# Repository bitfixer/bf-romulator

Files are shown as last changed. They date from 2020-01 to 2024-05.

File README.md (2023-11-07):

# bf-romulator
Romulator - RAM/ROM replacement and debug for 6502 and Z80 CPU systems

romulator - verilog code to implement ROMulator RAM/ROM replacement

programmer - programmer and console application for updating ROMulator, and debug

tools - C++ tools for building firmware images for ROMulator

## About

The ROMulator is a RAM/ROM replacement device for 6502 and Z80 systems, with programmable memory maps and debug functionality which allows you to halt a running CPU and read from or write to memory. See https://bitfixer.com/romulator for more information.

This Readme mostly covers the 6502 version for now, more documentation coming soon for Z80.

## Installation

To use the ROMulator, first remove the 6502 CPU from its socket on the PET (or other computer)'s motherboard.
**Note the orientation of the notch on the 6502 chip in the socket.**
Insert the 6502 chip into the 40-pin socket on the ROMulator board. Make sure the notch on the chip is aligned with the notch on the ROMulator socket.
Then, take the ROMulator board, and using the pins on the underside of the board, insert it into the 6502 socket on the motherboard.
**Make sure the notch on the 6502 chip is pointing in its original direction.**
If the ROMulator is inserted backwards, this may damage the ROMulator board since 5v will be presented where it shouldn't be.
Just make sure to double check:
- Original orientation of 6502
- 6502 chip notch should match with notch in ROMulator socket
- When inserting ROMulator into 6502 socket, 6502 chip should be in its original orientation

## Default Switch Settings

The ROMulator supports up to 32 memory maps. The default memory maps shipped with the ROMulator are currently mostly related to the Commodore PET, but you can add any maps you want via the programming interface. Over time more configurations for common 6502 computers will be added. Please note that these settings reflect the head commit of the repository, and may differ from the default settings on your ROMulator depending on when it was programmed. Building the latest version with `make program` after a `git pull` will generate the settings as described.
The default switch settings are as follows:

|Set Index  |Setting |Switch 1 |Switch 2 |Switch 3 |Switch 4 |
|---|---|---|---|---|---|
|0 |BASIC 2, NON-CRTC, Business Kbd  (i.e. 2001) |Off |Off |Off |Off |
|1 |BASIC 4, NON-CRTC  (i.e. 2001) |On |Off |Off |Off |
|2 |BASIC 4, CRTC, 80C (i.e. 8032) |Off |On |Off |Off |
|3 |BASIC 4, CRTC, 40C (i.e. 4032,4016) |On |On |Off |Off |
|4 |BASIC 4, PET 4032 60Hz |Off |Off |On |Off |
|5 |BASIC 2, NON-CRTC, Normal Kbd (i.e. 2001) |On |Off |On |Off |
|6 |BASIC 4, PET 4032 50Hz |Off |On |On |Off |
|7 |BASIC 4, PET 4016 60Hz |On |On |On |Off |
|8 |Apple II plus |Off |Off |Off |On |
|9 |BASIC 1, PET 2001-8 |On |Off |Off |On |
|10 |VIC-20 PAL |Off |On |Off |On |
|11 |VIC-20 NTSC |On |On |Off |On |
|12 |NOP Generator |Off |Off |On |On |
|13 |PETTESTER |On |Off |On |On |
|14 |PET Low RAM Test |Off |On |On |On |
|15 |PET RAM/ROM/VRAM Test |On |On |On |On |

The memory maps are defined in [config/memory_set_default.csv](config/memory_set_default.csv).
This file indicates which ROMs are located at which memory address.

## Adding Configurations for New 6502 Machines

This topic is big enough to have its own readme, and it is located here:\
[config/README.md](config/README.md)

## Program / Debug

Programming and Debugging with the ROMulator can be done in one of two ways:
- using a Raspberry Pi connected to the ROMulator's 10-pin header, or
- using a standalone programmer consisting of a D1 Mini Board (dev board for ESP12 wifi microcontroller module) and an interface board for connecting to the ROMulator. This method allows uploading new firmware over a wifi network as well as a direct connection to a Win/Linux/Mac using usb.

### Program / Debug with Standalone Programmer over WiFi or USB
Information on programming and debugging using the standalone programmer can be found here:\
[ROMULATOR_STANDALONE.md](ROMULATOR_STANDALONE.md)

### Program / Debug with Raspberry Pi
Programming or Debug functionality of the ROMulator uses a Raspberry Pi using a soft SPI implementation. 
You can use the optional RPI ROMulator programming board, or directly connect the following RPI physical pins to the corresponding pins on the 10-pin header on the ROMulator FPGA board:

|RPI |FPGA Hdr|FPGA Hdr |RPI |
|---|---|---|----|
|19 |1 (MOSI)|2 (3.3v) |17  |
|24 |3 (CS)  |4 (DBG)  |36  |
|22 |5 (RST) |6 (CDONE)|11  |
|23 |7 (SCK) |8 |NC  |
|21 |9 (MISO)|10 (GND) |34  |

If you are only programming and not running the debug client, DBG and CDONE are optional.
Take a look at this wiring diagram for a visual aid:
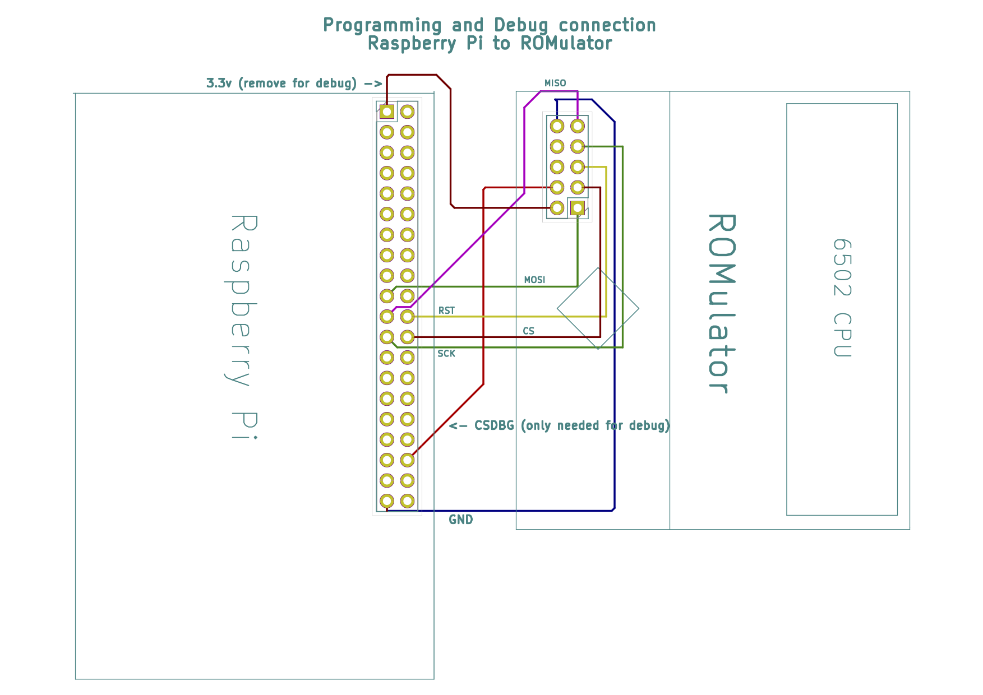
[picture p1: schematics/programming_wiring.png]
programming/debug diagram


# ROMulator programming board

The optional RPI ROMulator programming board is just a breakout board for SPI and UART on the Pi which brings SPI0 and SPI1 pins out to separate headers, as well as a UART header. The ROMulator only uses the SPI0 header. If you received a kit for this board, here are a few quick notes on the assembly.
1. Solder header pins onto the TOP of the board in the section marked 'SPI0'.
2. Solder a 2-pin header onto the header section directly adjacent to SPI0.
3. Solder the 2x20 socket onto the BOTTOM of the board.
4. Connect the jumper onto the 2-pin header for programming. Remove for debug.
5. When attaching the board to the raspberry pi, the headers face away from the body of the raspberry pi. Depending on how the connectors are attached to the ribbon cable, it may be connected in one of two ways. Just make sure there is no twist in the cable. See these images for reference:

<table>
  <tr>
    <td>If your cable looks like this:</td>
    <td>Connect it like this.</td>
  </tr>
  <tr>
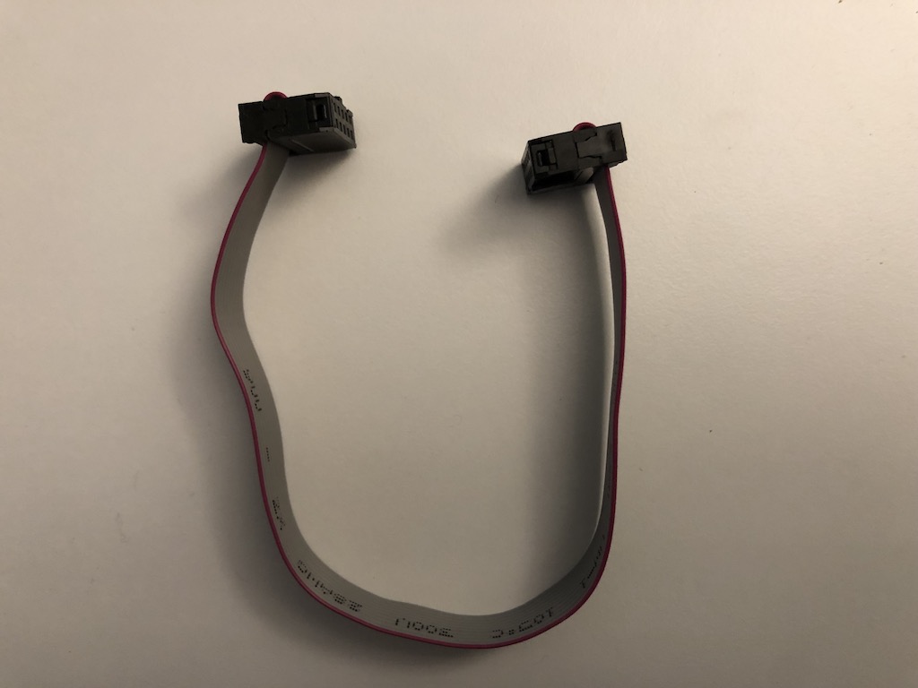
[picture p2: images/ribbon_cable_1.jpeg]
    <td></td>
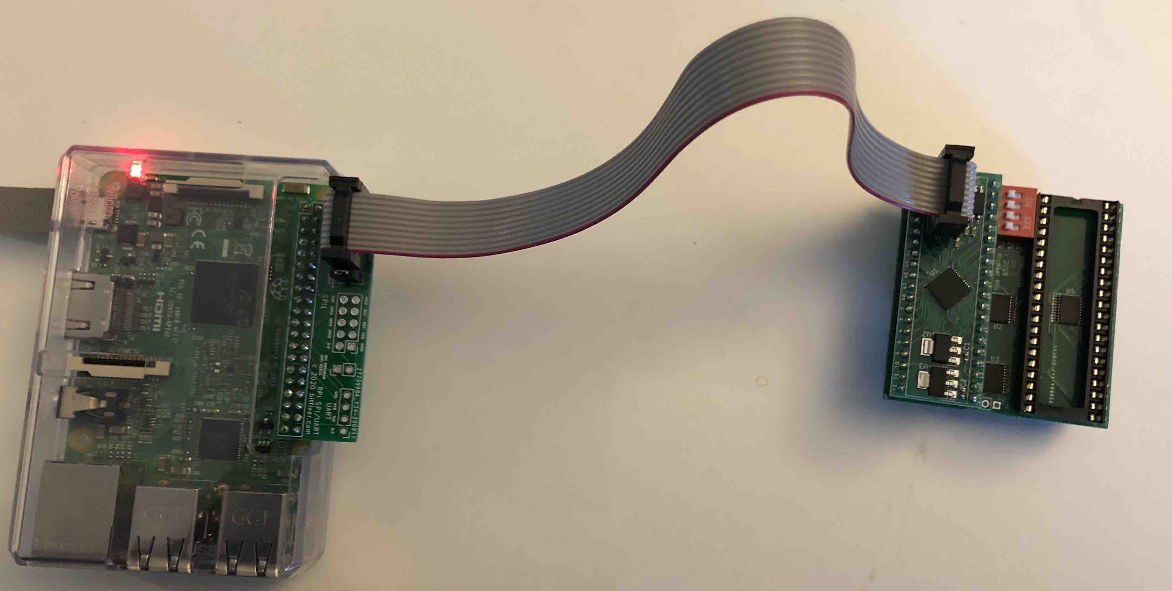
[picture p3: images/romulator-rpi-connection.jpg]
    <td></td>
  </tr>
</table>

Or,

<table>
  <tr>
    <td>If your cable looks like this:</td>
    <td>Connect it like this.</td>
  </tr>
  <tr>
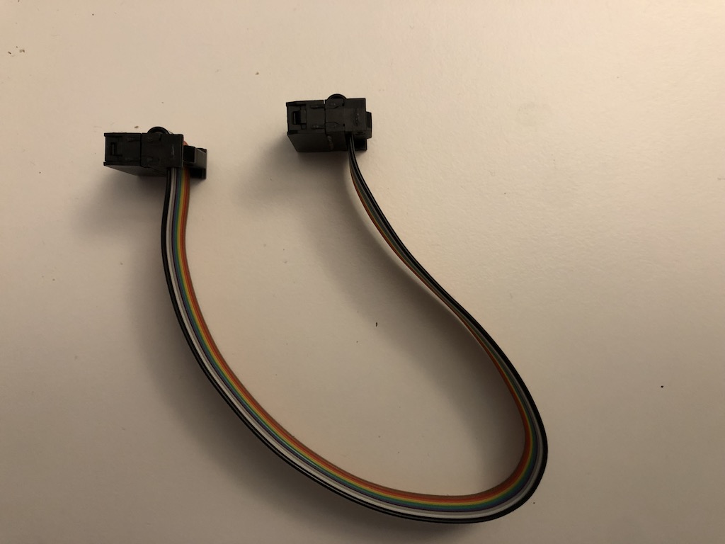
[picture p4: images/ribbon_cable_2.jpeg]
    <td></td>
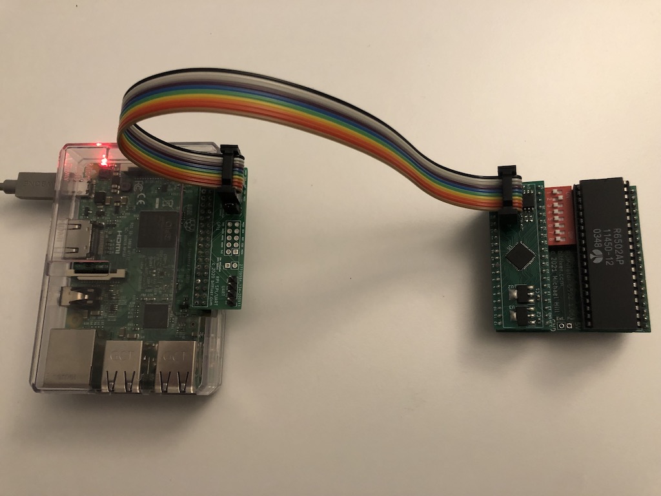
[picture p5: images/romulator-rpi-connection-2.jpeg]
    <td></td>
  </tr>
</table>

Please follow this procedure to enter debug mode on the romulator and read the contents of a running CPU.
1. run ```make bin/console``` from bf-romulator directory
2. run ```make debug``` to set appropriate pin directions on the pi. Specifically, this sets the DBG line to 1 to allow the ROMulator to start and not be stuck in a halt state, and sets the RST line to an input to avoid holding the fpga in reset.
3. If you are using the optional RPI programming board, remove the programming jumper.
4. run ```bin/console -r > output.bin``` to halt the cpu and read the full memory map into a file called output.bin.

### Installation

To install the ROMulator software on a Raspberry PI for programming or debug, download the script [setup.sh](https://raw.githubusercontent.com/bitfixer/bf-romulator/master/setup.sh) onto your Pi and execute from your home directory.
This will install the prequisites and fetch the latest version of the code in this repo.

The one-liner for this on the command line is:\
```wget -O - https://raw.githubusercontent.com/bitfixer/bf-romulator/master/setup.sh | sudo bash```

### Programming

To program a new firmware onto the ROMulator, run\
```make program```\
from the ~/bf-romulator directory.

Note that you will need all of the roms present in order to complete the build.\
This means that every unique rom specified in [config/memory_set_default.csv](config/memory_set_default.csv) to be present in the bf-romulator/roms directory.\
For convenience if you are downloading ROM images from a single source, there is a script which will do this for you.\
If you were downloading every rom with the base url of http://bitfixer.com, you would run the command:\
```BASEURL=http://bitfixer.com make fetch_roms```\
This downloads every unique rom specified in [config/memory_set_default.csv](config/memory_set_default.csv) to the roms directory.

## Programming Custom Firmware

If you just want to program a custom .bin file (if I send you one, for example) the procedure is a bit simpler.
Before the first time doing this run\
```make bin/programmer_spi```\
from the ~/bf-romulator directory.

Then, copy the custom .bin file somewhere on your raspberry pi, and run\
```bin/programmer_spi < customfirmware.bin```\
from the ~/bf-romulator directory, replacing customfirmware.bin with the actual path of that file.

## Virtual Display

A recent feature added to the ROMulator is the ability to create a virtual external display, using a connected Raspberry Pi as a webserver. By pointing a browser to the pi server, you will be able to 'see' the contents of video ram in realtime rendered into bitmap images.\
Currently, only the PET 2001 is supported, but other 6502 machines with memory-mapped graphics will be added soon.\
To use the virtual display feature on a PET 2001, connect the ROMulator to the 6502 socket on the pet, and connect the Pi via the interface board with the programming jumper OFF. For now only setting 1 (Sw 1 ON, rest OFF) is supported, which is BASIC 4.\
Power up the PET as usual, and the ROMulator LED should blink on for about one second. Then from the console on your Pi, from the bf-romulator directory, run:\
```make webserver```\
Then open a browser on another computer on the same network as the Pi, and navigate to the pi's server, like so:\
```http://raspberrypi.local:10000/canvas.html```\
Please note that while the pi will usually show up as raspberrypi.local, this is not always the case and you may need to know the actual local IP. At this point you should be able to enjoy a roughly 15-20 FPS PET 2001 display in your browser!

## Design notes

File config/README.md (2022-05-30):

# bf-romulator : Config

This directory contains configuration files which are used to build memory maps for the ROMulator.

Using the ROMulator in any 6502 machine requires configuration of two things: A memory map, and an enable table.

## Memory Maps

A memory map is comprised of a list of ROM files along with memory addresses where these ROMs should be placed in memory.\
Each entry in the memory map in referred to by a number, what we call the set index. Let's look at a couple of examples in the default memory map used by the ROMulator.

### memory_set_default.csv:

This file contains a list of which ROM images should be placed at specified memory addresses in memory maps for the ROMulator.
The format is:

|Set Index	|ROM Filename	|Memory Address in hex i.e. 0xFFFF	|

You can include comments in this file by starting the line with a # character.

Let's look at an example - the memory map for a PET 4032.\
Here's the section in the memory_set_default.csv file for this entry:

```
# PET 4032
4,basic-4-b000.901465-23.bin,0xb000
4,basic-4-c000.901465-20.bin,0xc000
4,basic-4-d000.901465-21.bin,0xd000
4,edit-4-n.901447-29.bin,0xe000
4,kernal-4.901465-22.bin,0xf000
```

This entry has the set index 4. This number maps to a switch setting on the ROMulator's dip switches. Each switch is a binary digit, starting with switch 1 as the least significant bit.\
So index 4 equals binary 0100. The 1s digit maps to switch 1, the 2s digit maps to switch 2, etc. Index 4 would be Switch 1 OFF, Switch 2 OFF, Switch 3 ON, Switch 4 OFF.

The second column in the entry is the name of a binary file with the contents of a ROM that should be loaded. These files should be located in the #roms# directory.

The third column is a memory address in hex indicating the start addres of this particular ROM.

Currently the ROMulator supports up to 32 memory maps (indices 0-31).

To support a new 6502 machine, first get a list of the ROMs for that machine, and the memory locations where they should be placed. Then you can add an entry to memory_set_default.csv for your configuration. You can also make an entirely separate csv file, this is covered a bit later.

## Enable Tables

The second half of a configuration for the ROMulator is the enable table. This is a list of ranges in memory space specified by a start and end address, and a keyword which indicates how that section of memory should be handled by the ROMulator. 
The default enable table is defined in the following file:

### enable_table_default.csv

Similar to a memory map, each line of the enable table has the format:

|Set Index (or range of indices)|Start Address in Hex|End Address in Hex|"Keyword"|

Let's look at the example for setting 4 again, for the PET 4032.
The first few lines of the enable table file are:
```
0-14,0x0000,0x7FFF,"readwrite"
0-14,0x8000,0x8FFF,"writethrough"
0-14,0x9000,0xAFFF,"passthrough"
0-14,0xB000,0xE7FF,"readonly"
0-14,0xE800,0xEFFF,"passthrough"
0-14,0xF000,0xFFFF,"readonly"
```

Each of these lines has a range of indices specified instead of a single index.\
Examine the first line:
Set indices are 0-14. This means to use this setting for all switch settings between 0-14, inclusive.
Start address is 0x0000, and end address is 0x7FFF. This means the setting applies to this range of addresses. The end address is inclusive.
Then the keyword is "readwrite". This means for this range, we want to use the ROMulator's onboard memory to override any reads or writes to these addresses.

You can specify ranges of indices like this as a shortcut to save you from duplicating the same entries for a series of settings that are the same or nearly the same, as is the case with a group of similar PET computers. 

These lines can be overridden later in the file as is done with this entry:
```
# only enable 16k ram for 4016
7,0x0000,0x3FFF,"readwrite"
7,0x4000,0x7FFF,"passthrough"
```

In this case, for index 7, we override the previously specified keyword for these regions of memory, which effectively disables region 0x4000-0x7FFF on the ROMulator, meaning that the PET 4016 only detects 16k of memory. An example of how you can override range settings.

### memory enable keywords

The following keywords are used in this table:
* "readwrite" : fully replace any read or write to this range. This is used for RAM that you wish the ROMulator to replace.
* "readonly" : replace any read to this range with the ROMulator's memory, and disable writes. This is used for ROMs.
* "passthrough" : reads and writes to this region should go through to the mainboard and not be intercepted by the ROMulator. This is used for I/O.
* "writethrough" : writes to this region are done both to the mainboard and to the ROMulator. Reads are read from the mainboard. This is useful for sections of memory that are read by something other than the CPU, which is often the case with video RAM.

Adding an enable table entry or entries for a new 6502 machine means learning the memory map for that machine and defining the regions of memory directly in enable_table_default.csv or in a separate csv.\
Generally to replace RAM, use "readwrite". To replace ROM, use "readonly". IO regions should be "passthrough" and video ram would usually be "writethrough". Any other section you don't want the ROMulator to touch would be "passthrough".

Currently, the smallest independently configurable region is 256 bytes. This is somewhat arbitrary and could be smaller if needed with a software change, it just uses more block RAM on the FPGA to do so.

Once you have set up your memory map and enable table, and have gotten all your ROM files into the roms directory, then you are ready to load the new firmware with your configuration: See https://github.com/bitfixer/bf-romulator#programming to do this.

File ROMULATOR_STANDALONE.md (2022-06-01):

# Programming/Debug using Standalone Programmer

## Assembly

The following images show the assembly of the standalone programming/debugging kit, as well as how to connect to the ROMulator.

<table>
  <tr>
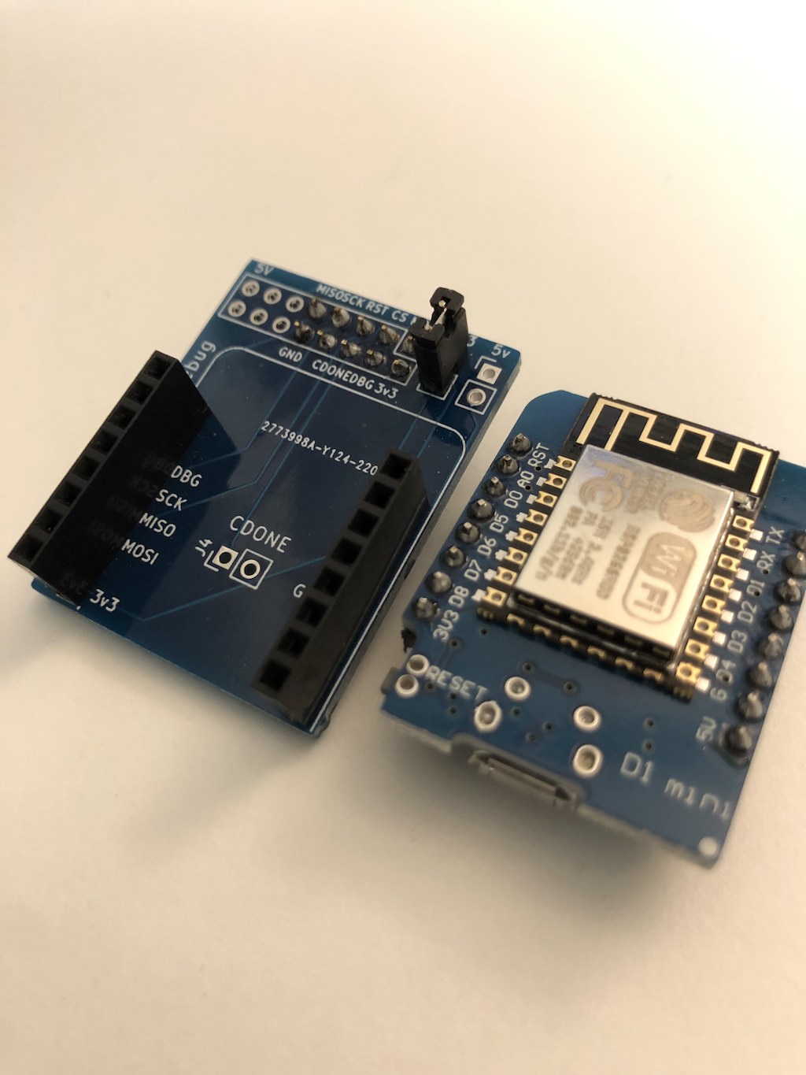
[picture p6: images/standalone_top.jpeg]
    <td></td>
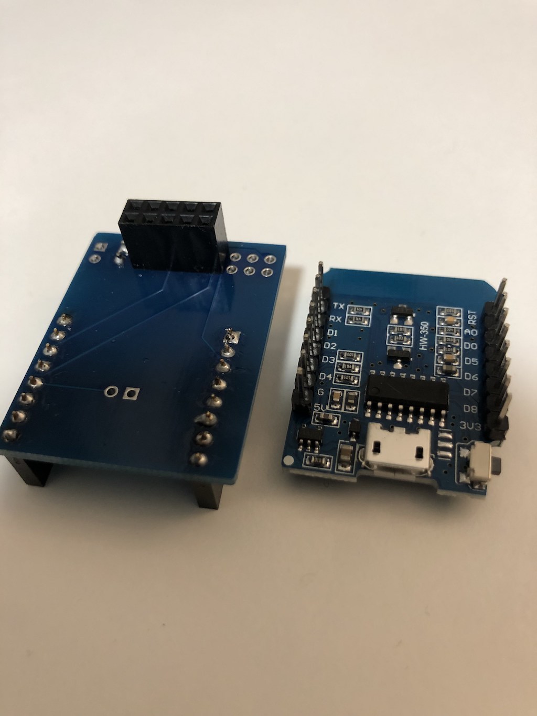
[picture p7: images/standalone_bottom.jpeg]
    <td></td>
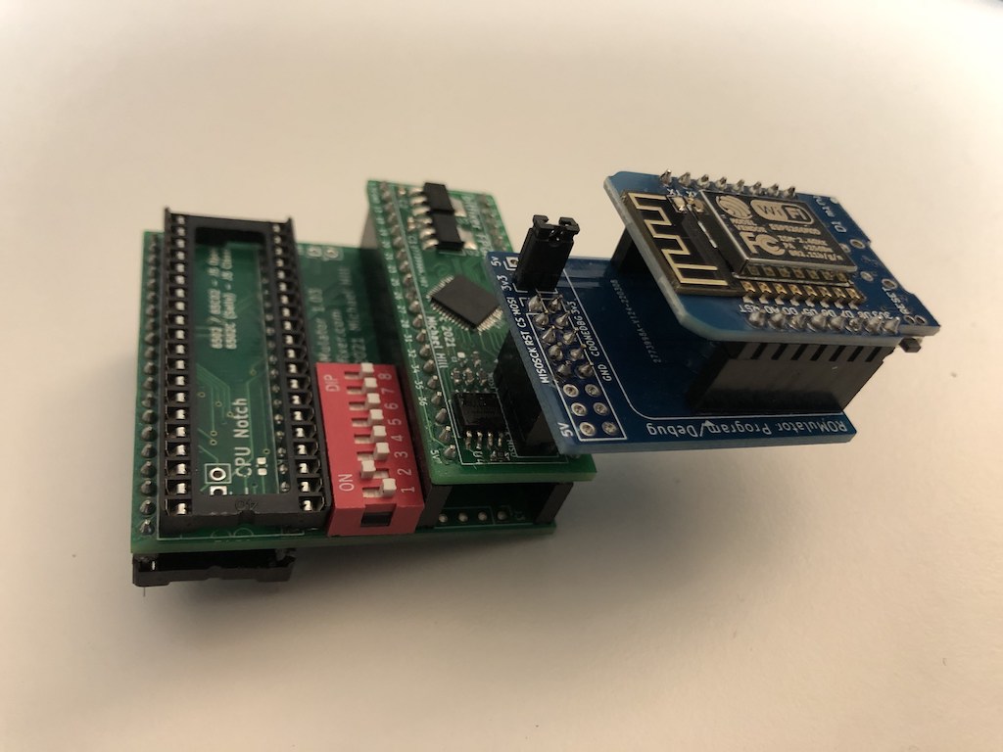
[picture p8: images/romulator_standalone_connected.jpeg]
    <td></td>
  </tr>
</table>

The standalone programmer for the ROMulator consists of a D1 Mini board and an interface board to connect the D1 Mini to the ROMulator's 10-pin header.

# Creating firmware images

To create new firmware files for your ROMulator, you can use a web-based tool to create them without needing any installation.\
Create or modify existing memory set and enable table files to include your desired settings. Then get any ROM binary files which are not also referenced in the ROMulator's default firmware. Put your enable table and memory set files (need to start with 'enable_table' and 'memory_set' and have a .csv extension) along with these ROM files into a zip file with no subdirectories.\
Then go to the [ROMulator Build](http://bitfixer.com/romulator-build) page.\
Here you can upload your zip file, and you will get back a file named 'romulator.bin' which you can directly program onto the device as described below.\
If you want to change fundamental behavior of the ROMulator by modifying verilog files and not just changing ROMs and enable tables, see the [advanced](#advanced) section below.

# Setting up the standalone programmer

Using the standalone programmer, you can program/debug through a web interface once the programmer has connected to your WiFi network, or you can program using a serial terminal program while connected to USB.

If you are using your own D1 Mini board, you will first need to program it with debugging/programming firmware which is described here. If you ordered the standalone programmer kit from bitfixer.com, it will come pre-programmed and you can skip ahead, although you will need to do this to install any firmware updates.

## Programming D1 Mini

To program the D1 Mini with the romulator debug/program firmware, you need to build and install with platformio. I will describe how to do this using platformio as a plugin to Visual Studio Code, it is also possible to do this with platformio as a pure command line installation, but I find the VSCode method easier to use.

Install [Visual Studio Code](https://code.visualstudio.com/) on your computer (Mac/Linux/Windows), free download for all platforms.\
After install, launch and then select 'Extensions' (View->Extensions). Search for 'PlatformIO IDE' and install the plugin.\
After this, open the 'romulator-programmer-debugger' directory in File->Open Directory (or Open Folder).\
PlatformIO will do some installation and eventually ask you to restart VSCode.\
Do this, then connect to the D1 Mini board with USB and eventually you should see a right arrow on the bottom bar of the IDE (the tooltip is PlatformIO: Upload).\
Select this. You may see a message to the effect that 'romulator-programmer-debugger.upload' does not exist - in this case just wait and try again, PlatformIO is doing something in the background. Eventually this will work and build and install on your D1 Mini. It is possible you may have to specify a value for 'upload-port', which will be the id of a serial port on your system, but generally it will auto-detect this.

After programming the board, you will also need to upload a filesystem image onto it. This contains some files needed to run the web interface on the D1 Mini.\
To do this, select the PlatformIO menu (on the toolbar located on the left of the VSCode window, a little alien face) and then Platform->Upload Filesystem Image.\
This will upload the needed files to the D1 Mini. Now you are done!

## Web Interface

Power up your D1 Mini. On first power-up the LED will start blinking. After a few seconds, on a device of your choice, connect to the wifi network 'romulator'. This will have a password of 'bitfixer'.\
Then in a browser go to 192.168.4.1. This will bring up a page which allows you to enter the name and password to connect to your wifi router. After doing this, you are prompted to reset the D1 Mini.

At this point, your standalone programmer is ready to go. Connect the D1 Mini to the interface board, and then connect to the ROMulator as shown [here](#assembly).

Now you can power up, and wait for the blinking LED to stop blinking and be solidly on. This indicates that the board has successfully connected to your router and is now on your wifi network.

Here is one tricky part. The D1 Mini is supposed to be able to self-report a hostname, much like the raspberry pi does on your local network (raspberrypi.local). This would be convenient, since you could refer to this address rather than needing to know the local IP that your router happens to assign to the device. However, I was not able to get this to work, despite trying sample code exactly which claimed to do this. Possibly a router misconfiguration on my part. Feel free to let me know if you have any insights on this.\
For this reason, I added a simple redirect service hosted on my site, bitfixer.com.\
Once the D1 Mini successfully connects to your network, it makes a single request to http://bitfixer.com/rmltr/r.php. Included in this request is the local IP address the device was given by your router.\
After your D1 Mini connects, you can then reach its web interface by going here:\
[http://bitfixer.com/myromulator](http://bitfixer.com/myromulator)\
This reads the IP of the incoming request, which will match the IP of the D1 Mini since they are on the same network, and will redirect you back to the D1 Mini's local IP. This allows you to reach the web interface without knowing the specific local IP.\
You can also just check the local IP of the device on your router as well and connect directly to it, either method works.

Once connected to the web interface, you can program the ROMulator with the firmware you built, which will be in bin/romulator.bin in the bf-romulator directory. Just select 'Program' on the webpage and then select this file, and wait until the upload and programming completes. That's it!

## Serial Interface

It is also possible to program the romulator using a serial terminal, without using the web interface at all.

To do this, when connected to the D1 Mini with USB, launch a terminal program that supports serial ports and Xmodem file transfer. Good examples are minicom on mac/linux, or TeraTerm on Windows. Set the baud rate to 115200.

You will need to find the id of the serial port on the D1 Mini. This id varies but has some commonalities. On Mac/Linux, try ```ls /dev/tty.usb*``` or ```ls /dev/tty*```. This will show some possible device names, you can try disconnecting the device, listing, then connecting and listing again to find which id shows up. If there is a better way to do this, please let me know.\
On Windows, it often shows up as COM6 or COM7, generally the first com port over COM2 is the one. If the terminal shows a name associated with each com port, it will be the one with a name like 'usb-to-serial' something.

Once connected with the right baud rate, hit the reset button on the D1 Mini. A menu should show up in the terminal. To program, type 'p' for the programming menu and then 'p' again to program firmware. You will be prompted to send the file using XMODEM, then go ahead and using the menu on your terminal program, select bin/romulator.bin and start the transfer. This will upload the file to the device and program the romulator.

## Advanced

If you are planning to do more than changing ROMs in memory sets and the enable tables, like changing verilog files to modify the basic functionality of the ROMulator, then you will need to set up the build system on a Win/Mac/Linux machine.\
First step is to install the build tools on your Win/Mac/Linux machine. You will build new firmware images here. For Mac and Linux the install is fairly straightforward and just requires running a script. On Windows, however, some build dependencies are not natively supported, and requires installing a Linux distro using WSL (windows subsystem for linux). 
Instructions for each OS:

## Windows

Use the Microsoft Store to install a linux distribution with apt as a package manager. Either Ubuntu or Debian recommended.\
After installation, your windows filesystem is accessible in /mnt, i.e. C: is at /mnt/c/, etc.\
Create a directory for your installation somewhere easily accessible to both linux and windows, i.e. /mnt/c/home/Users/username/romulator. Change to this directory and follow the instructions for Linux at this point.

## Linux

Create a directory for your install.\
Then fetch and run the linux setup script from linux command line in this directory with (one line)\
```wget https://raw.githubusercontent.com/bitfixer/bf-romulator/master/setup_linux.sh; ./setup_linux.sh```\
You will need to enter your password as some commands in the setup script require sudo.

## Mac (10.15 or higher)

If not installed already, install homebrew using instructions here.:\
[homebrew installation](https://brew.sh)\
Create a directory for your romulator installation.\
Then open Terminal, change to the install directory, and run this (one line):\
```curl https://raw.githubusercontent.com/bitfixer/bf-romulator/master/setup_mac.sh > setup_mac.sh; chmod 755 setup_mac.sh; ./setup_mac.sh```\
You will need to enter your password at some point during the installation.

# Programming

To build firmware, in a terminal run\
```make romulator```\
from the bf-romulator directory. The firmware file will be bin/romulator.bin.

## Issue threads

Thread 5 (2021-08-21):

Raspberry Pi Zero support?

lagomorph, 2021-08-21:
Any chance of building this on a RPi Zero? Looks like apio doesn't support linux_armv6l.

bitfixer, 2021-08-22:
Hi John,
Thanks for the information,
I was not aware that apio didn't support the zero, that's too bad. I hadn't
tried it on mine.
An alternative that I often do to get faster build times is to install apio
and its dependencies on another machine, do builds there, and then just use
the pi for programming the device from the binary and for debugging. Apio
installs on Linux, on a Linux flavor installed with the Linux subsystem on
windows (what I generally use), and will also install on Mac OS as well.
Then you can build the ROMulator image from there with "make
bin/romulator.bin", scp the file to the pi and then "bin/programmer_spi <
romulator.bin" to program the device. Happy to help with this, please let
me know if you have any questions. Thanks
Mike
***@***.***

On Sat, Aug 21, 2021 at 3:19 PM John Scarfone ***@***.***>
wrote:

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

lagomorph, 2021-08-22:
No problem, Mike. I'll probably end up building on MacOS. Thanks.

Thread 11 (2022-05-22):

Cannot get fetch_roms.py working. Ubuntu server and Windows wsl ubuntu

dabonetn, 2022-05-22:
Issuing the command 'BASEURL=http://bitfixer.com make fetch_roms' I get the following error.
I also get this trying to use the zimmers pet rom directory as the base.

Traceback (most recent call last):
  File "../tools/fetch_roms.py", line 26, in <module>
    for row in romreader:
_csv.Error: iterator should return strings, not bytes (did you open the file in text mode?)
make: *** [Makefile:85: fetch_roms] Error 1

Any suggestions?

lagomorph, 2022-05-23:
You could try changing line 24 of fetch_roms.py from:
  with open(csvfile, 'rb') as csvfile:
to:
  with open(csvfile, 'r') as csvfile:

python3 wants it to be opened in text mode

bitfixer, 2022-05-25:
Sorry for the delay, will give this a try on ubuntu today to see what I can
find. Sounds like it may indeed be that file mode switch.

On Mon, May 23, 2022 at 12:57 PM John Scarfone ***@***.***>
wrote:

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

dabonetn, 2022-05-25:
Installing python2 python-is-python2  got it working. apparently python3 is the default for newer installs.

lagomorph, 2022-05-25:
As of January 1st, 2020 python2 is no longer supported either.

bitfixer, 2022-05-26:
I ditched the python script and rewrote the fetcher in c++, pushed up to
master. Should work now with BASEURL=<url> make fetch_roms.

On Wed, May 25, 2022 at 3:16 PM John Scarfone ***@***.***>
wrote:

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

cvpeck, 2022-05-26:
Python 2 is now deprecated on all platforms. Migration to Python 3 is recommended

Sent from my iPad

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

dabonetn, 2022-05-28:
Just build a new vm and the new fetch rom now works.

The only complaint I have now, is that if you go ahead and do a git clone to grab the romulator tree, (instead of just grabbing the setup script)
and then run setup_linux.sh, it completes, and says everything is good, but then when you make romulator, it fails because
everything is actually setup in a bf-romulator/bf-romulator directory.

Maybe add a check to see if you are already in the bf-romulator directory when running the setup script?

bitfixer, 2022-05-28:
Good idea, will do that.

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

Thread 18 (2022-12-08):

The romulator FPGA image doesn't always meet timing when minor modifications are made to the verilog code.

dennowiggle, 2022-12-08:
I found that when modifying FPGA verilog code that even though the code builds correctly without errors using the provided tools and scripts it doesn't always run correctly. Sometimes even removing a few lines of non-called verilog code will result in the FPGA going from working to not functioning at all, or partially functioning. Such as random spi errors causing partially missing data and a distorted image on canvas.html web page.

After going around in circles for many days I found that the recompiled verilog images likely did not meet timing despite no warning.

The installation instructions and script provided forces apio version 0.5.4 and uses the FPGA tools and versions assigned to this apio version. In windows subsystem for linux later versions of apio and tools will build the romulator image but with timing errors. (Note, only Raspberry Pi 64bit OS is supported in the newer tools for those using that for synthesizing/placing/routing). I upgraded to apio version 0.8.1 in WSL debain and timing errors are reported with this latest version. For example :

"ERROR: Max frequency for clock 'romulator.clk': 34.93 MHz (FAIL at 48.00 MHz).

Changing the clk clock frequency from 48MHz to 24MHz resolved the timing error reported by the packages in apio 0.8.1 and converted non-working code built by apio tools installed on version 0.5.4 to working.

I made the following clock change to the verilog code in enable_logic.v :

Chnage line from :
    SB_HFOSC #(.CLKHF_DIV ("0b01")) inthosc(.CLKHFPU(1'b1), .CLKHFEN(1'b1), .CLKHF(clk));
to
    SB_HFOSC inthosc(.CLKHFPU(1'b1), .CLKHFEN(1'b1), .CLKHF(clk));

dennowiggle, 2022-12-11:
I still have apio version 0.5.4 installed on my Raspberry Pi. I synthesized the original FPGA verilog code from github and then ran a timing analysis with the command "apio time" that showed a max clock of 21MHz. This was the output.

[Sun Dec 11 08:11:36 2022] Processing upduino
----------------------------------------------------------------------------------------------------------------------------------------------------------------
icetime -d up5k -P sg48 -C "/home/pi/.apio/packages/toolchain-ice40/share/icebox/chipdb-5k.txt" -mtr hardware.rpt hardware.asc
// Reading input .asc file..
// Reading 5k chipdb file..
// Creating timing netlist..
Warning: timing analysis not supported for cell type HFOSC
// Timing estimate: 46.01 ns (21.74 MHz)
================================================================= [SUCCESS] Took 8.01 seconds =================================================================

I did play with the Lattice tool Radiant. Unfortunately Lattice & Synplify tools do not support initial conditions, despite the FPGA and yosys supporting them, so I can't generate a functional image to compare like with like. However I did see that Radiant also cannot meet timing and that the CRC32 design is where the critical timing path is. Another approach to generating CRC32 might improve timing there but lowering the clock to 24MHz and using the latest apio also works.

Hope that helps.

dennowiggle, 2022-12-11:
While VRAM reads work now, this was in standalone mode (not plugged into the computer). When romulator is plugged into the computer the computer no longer works. I'm guessing timing of the address/data bus is messed up.

I will try and take a look in the week and learn about PLL's to see if they could be a solution. Perhaps constraints might help......

dennowiggle, 2022-12-12:
A 24Mhz clock does work and meet timing if I back out the typo changes in "spi_flash_reader.v" detailed in thread for issue #19
https://github.com/bitfixer/bf-romulator/issues/19#issuecomment-1344852337

My test computer is an Apple IIe which boots, runs code, and displays a 40 column mode remote screen on canvas.html with other changes I am playing with.

A more thorough approach to cleaning up the typo's in "spi_flash_reader.v" is still needed..........

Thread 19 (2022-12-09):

Parity Error Check Bug - When D1-mini sends 0x22 for a reread after a parity error the FPGA does not decrement the address by 8.

dennowiggle, 2022-12-09:
This was tested on the D1-mini by forcing a send of 0x22 to the FPGA at a specific vram address and looking at the data returned by the FPGA - using the initialized memory with predefined pattern defined by file vram_test.txt.

The error in the FPGA code is in the VERIFY_PARITY_BYTE section of the state machine in "diagnostics.v". Change line 219 from "if (rx_dv <= 1'b1)" to "if (rx_dv == 1'b1)"

    VERIFY_PARITY_BYTE:
    begin
      tx_dv <= 0;
      // if (rx_dv <= 1'b1)
      if (rx_dv == 1'b1)
      begin
        if (rx_byte == PARITY_ERROR)
        begin
          vram_address <= vram_address - 8;
        end
        state <= NEXT_VRAM_BYTE;
      end
    end

Now that "if (rx_dv == 1'b1)" is functioning properly, the D1-mini code needs to be modified in file "libRomulatorDebug.cpp".

Between lines 356 and 357 add
        // Advance FPGA so it can prepare the next vram byte for sending over SPI.
        rx_byte = xfer(0x0);

A similar change should also be made on the Raspberry Pi code for that version of debugger.

dennowiggle, 2022-12-09:
There are a few other typo's and I've noted them below.

In file "diagnostics.v" there is also an error on line 165 where an "=" is used instead of "<="
change line 165, from
      parity_byte[parity_counter] = vram_data[0] + vram_data[1] + vram_data[2] + vram_data[3] + vram_data[4] + vram_data[5] + vram_data[6] + vram_data[7];
to :
      parity_byte[parity_counter] <= vram_data[0] + vram_data[1] + vram_data[2] + vram_data[3] + vram_data[4] + vram_data[5] + vram_data[6] + vram_data[7];

Some of the other verilog files have similar typo's.

"enable_logic.v"
* Extra comma on line 337 can be removed
    .q(vram_output),

"spi_flash_reader.v"
Line 180 change
            state = TX_IDLE;
to
            state <= TX_IDLE;

line 194 from
            xfer_state = XFER_IDLE;
to
            xfer_state <= XFER_IDLE;

line 218 from
            xfer_state = XFER_FLASHREAD_BLOCK;
to
            xfer_state <= XFER_FLASHREAD_BLOCK;

line 223 from
        xfer_flash_blocks_to_read = xfer_flash_blocks_to_read - 1;
to
        xfer_flash_blocks_to_read <= xfer_flash_blocks_to_read - 1;

line 235 from
                xfer_flash_blocks_to_read = 2;
to                            
                xfer_flash_blocks_to_read <= 2;

line 348 from
        ram_address = ram_address + 1;
to
        ram_address <= ram_address + 1;

"simple_ram_dual_clock.v" - line 14 is missing a semi-colon at the end
  reg [DATA_WIDTH-1:0] ram [2**ADDR_WIDTH-1:0]   // ** is exponentiation

bitfixer, 2022-12-11:
Thanks very much for the fixes! I am away from my computer for a few days
but will take a closer look as soon as I'm back.

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

dennowiggle, 2022-12-12:
Correction: File "spi_flash_reader.v"

Delete line 223
        xfer_flash_blocks_to_read = xfer_flash_blocks_to_read - 1;

Add line between line 290 and 291
        xfer_flash_blocks_to_read <= xfer_flash_blocks_to_read - 1;

New line should look like this
    XFER_READ_BYTES_DONE:
    begin
        spi_cs_reg <= 1;
        xfer_flash_blocks_to_read <= xfer_flash_blocks_to_read - 1;
        xfer_state <= XFER_FLASHREAD_NEXT;
    end

Changes have been tested to work with a 24MHz clock on an Apple IIe.

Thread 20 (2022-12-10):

65c02 Apple IIe Enhanced

Velkas, 2022-12-10:
Not sure if this is the right place but I just got my romulator put together and tested as working. I was hoping to use this to dig into my Apple IIe (enhanced). I noticed there are through holes for a jumper with the board silk screen showing to connect for a 65c02 which I have done. However there seems to only be a rom entry for the Apple II+ in the default enable and memory mapping.

I was hoping to get some help figuring out how to add an Apple IIe Enhanced entry since I have the system with upgraded rom that's been tested and working 100%,.

My understanding is that the dip switches on the romulator are for selecting the rom / memory map to load. So I would imagine I need to dump the rom from the machine, then somehow figure out a mapping. After that I would need to get those added into the firmware for the fpga?

To be honest I'm new to all this and part of why I want to get this working is to just learn more about the 6502 era of computing. This started with ben eater's fantastic 6502 breadboard computer kit which I also intend to program into the romulator eventually.

Anyways, some advice, steps, or general information would be helpful as I'm still getting oriented.

dennowiggle, 2022-12-10:
I have an Apple IIe Platinum and this is what I use for configuration. It probably needs tweaking some more but it's a good start. In my case the ROM overlaps the I/O area, but that is not the case in earlier models.

I did not need to use a jumper for the 65c02 that my machine has. I have managed to see code I loaded from disk at address 0x6000 using the D1-mini tool.

I found it best to remove all other configs for now to remove chance of errors. In my case having a line consisting of multiple spaces caused an issue as such a line with more that 2-3 spaces will be treated as a valid line. Also, avoid very long comments as they will overflow the buffer.

##############################################
File "enable_table_default.csv"

1,0x0000,0x03FF,"readwrite"
1,0x0400,0x07FF,"writethrough"
1,0x0400,0x07FF,"vram",characters-2.901447-10.bin
1,0x0800,0x0BFF,"writethrough"
1,0x0C00,0x1FFF,"readwrite"
1,0x2000,0x5FFF,"writethrough"
1,0x6000,0xBFFF,"readwrite"
1,0xC000,0xCFFF,"passthrough"
1,0xD000,0xFFFF,"readonly"

For now I'm using the PET character ROM for which Mike has code working. I have yet to get the remote screen fully working in 40 col mode on the Apple IIe as more code changes are needed but it will be possible given time. Basically the screen is mapped in a non linear way on the Apple II and is loacted at address 0x0400-0x07FF.

#############################################
File "enable_table_default.csv"

1,IIeP_C0-FF-342-0349-B.bin,0xc000

Find the ROM that your system uses on the interwebs and then in file "memory_set_default.csv" add a line for config 1. Place the ROM file in the ROM's directory. ROM's can be found here:
https://mirrors.apple2.org.za/Apple%20II%20Documentation%20Project/Computers/Apple%20II/Apple%20IIe/ROM%20Images/

#############################################
Hope that helps.

dennowiggle, 2022-12-10:
I just looked at the schematic and the CPU jumper you talk about in the first post is attached to pin 36 of the CPU which is Bus Enable on the WD65C02. If you are using that manufacturer (WDC) it is recommended to tie pin 36 to VDD on the IIe.
The romulator jumper connects 36 to RW which is different.
https://www.westerndesigncenter.com/wdc/AN-002_W65C02S_Replacements.php

Please note that this instruction is only needed for certain newer versions of the 65C02 such as the one currently sold by WDC. The WDC link above includes a comparison table for the different versions of 6502. So if you have an original Rockwell 65C02 then pin 36 is NC on that chip too and you don't need the jumper on the Romulator.

bitfixer, 2022-12-10:
Thanks very much for the fixes and contributions! I'm away from the
computer for a few days but will take a closer look as soon as I'm back.

On Sat, Dec 10, 2022 at 10:08 AM dennowiggle ***@***.***>
wrote:

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

Velkas, 2022-12-10:
This is fantastic!

Thank you so much. I'm going to start looking into it later today.

I do have the IIe platinum as well, and the chip is actually labeled 6503 but everything I could find online was that it is still just a 6502 from the enhanced chipset originally offered by Apple.

And the info for the WDC 6502 (which I'm using for my breadboard computer) will also be very useful.

I also got the D1 mini tool with the hopes to utilize the remote video.

I'll take a look for a rom online but I'm also trying to get my hands dirty here so I'll try dumping the rom myself soon too, assuming I'm on the right path by pulling it and using a my rom flasher to back it up (as far as I can tell with tests it has not degraded yet).

Thank you again!

Velkas, 2022-12-16:
>

Just wanted to follow up and say thank you! With your help I was able to get the memory map and rom mapping to work and my d1 can now halt the iie enhanced and can successfully interrogate the memory. I ended up using your map as a starting point and landed here:

```
1,0x0000,0x00FF,"readwrite"         # RAM Zero Page
1,0x0100,0x01FF,"readwrite"         # RAM 6502 Stack
1,0x0200,0x02FF,"readwrite"         # RAM Input Buffer
1,0x0300,0x03FF,"readwrite"         # RAM Vectors
1,0x0400,0x07FF,"writethrough"      # RAM Text/Lo-Res Gfx Page 1 Display
1,0x0800,0x0BFF,"writethrough"      # RAM Text/Lo-Res Gfx Page 2 Display
1,0x0C00,0x1FFF,"readwrite"         # RAM
1,0x2000,0x3FFF,"writethrough"      # RAM Hi-Res Gfx Page 1 Display
1,0x4000,0x5FFF,"writethrough"      # RAM Hi-Res Gfx Page 2 Display
1,0x6000,0xBFFF,"readwrite"         # RAM
1,0xC000,0xCFFF,"passthrough"       # IO (Default ROM)
1,0xD000,0xFFFF,"readonly"          # ROM
```

I was able to run multiple diagnostic and test programs to run and verify all the hardware and slots including the 80 col and double high-res display functions are working.

dennowiggle, 2022-12-17:
I'm happy to hear of your progress. Thank you for sharing the refined tweak with meaningful comments.

I did get the remote screen working in 40 column mode. Here is a temporary link for the changes to the D1-mini code that I made. I have forwarded these to the developer.
https://drive.google.com/file/d/1pQ_VnYD2h5_zkqTvuM6FKqLhmGsuENPe/view?usp=sharing

Instructions:
* modify data/enable_table.csv file to match your config.
* The character ROM I've included in the /data directory is for the IIe platinum but may work for other IIe's.
* Note : in file data/romulator.html I changed the html text to show the text 'WTM' as a way for me to easily see that this is modified code and not from the repository.
* You will need to rebuild and upload the romulator-programmer-debugger image in vscode and also for the filesystem - Instructions to do this are on github.
https://github.com/bitfixer/bf-romulator/blob/master/ROMULATOR_STANDALONE.md
* To view the screen live go to http://'Romulator IP address'/apple.html
* Some browsers do timeout after viewing for a little while. I suspect that is because of recursive javascript code. Firefox seems to handle this best.

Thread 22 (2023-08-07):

Issue with Romulator

laffineuse, 2023-08-07:
I just received and assembled the romulator but it doesn’t work in my Pet 8032.  The FPGA flashes once and then nothing, not even the chirp.  This is in a working PET with a working 6502.

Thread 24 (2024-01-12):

ERROR: IO 'dataout[7]' is unconstrained in PCF

FraEgg, 2024-01-12:
Hello Michael,

many thanks for the romulator 6502. it really is a great tool.

I have a problem with creating my own custom firmware. The "make program" process is always aborted with an error message. I just can't find the problem and hope you could give me a hint.

I am using a Raspberry Pi 3+ with the latest RaspianOS (64Bit).

When I generate the files via your website, the firmware works on the romulator.

Best regards Frank

Logfile:
```
pi@romulator:~/bf-romulator $ make program
gpio mode 27 out
gpio write 27 1
gpio mode 6 out
gpio mode 10 out
bin/programmer -b
mkdir -p bin
bin/build_enable_table /home/pi/bf-romulator/config/enable_table_default.csv bin/enable_table.bin > bin/enable_table.txt
mkdir -p bin
cd /home/pi/bf-romulator/romulator; rm -f input*.v; rm -f *.pcf
cp /home/pi/bf-romulator/romulator/6502/* /home/pi/bf-romulator/romulator
cd /home/pi/bf-romulator/romulator; rm -f hardware.*; apio build
(DEBUG) Profile path: /home/pi/.apio/profile.json
(DEBUG) Home_dir: /home/pi/.apio

PATH: /home/pi/.apio/packages/tools-oss-cad-suite/bin:/home/pi/.apio/packages/tools-oss-cad-suite/lib:/usr/local/sbin:/usr/local/bin:/usr/sbin:/usr/bin:/sbin:/bin:/usr/local/games:/usr/games

[Fri Jan 12 20:36:50 2024] Processing upduino
------------------------------------------------------------------------------------------------------------------------
yosys -p "synth_ice40 -json hardware.json" -q SPI_Master.v diagnostics.v enable_logic.v input6502.v ramenable.v simple_ram_dual_clock.v spi_flash_reader.v spi_slave.v sram.v sram64k.v
Warning: Yosys has only limited support for tri-state logic at the moment. (spi_slave.v:197)
Warning: Resizing cell port sram.ramfn_inst1.POWEROFF from 32 bits to 1 bits.
Warning: Resizing cell port sram.ramfn_inst1.SLEEP from 32 bits to 1 bits.
Warning: Resizing cell port sram.ramfn_inst1.STANDBY from 32 bits to 1 bits.
nextpnr-ice40 --up5k --package sg48 --json hardware.json --asc hardware.asc --pcf up5k.pcf -q
Warning: unmatched constraint 'spi_clk' (on line 1)
Warning: unmatched constraint 'spi_miso' (on line 2)
Warning: unmatched constraint 'spi_out' (on line 3)
Warning: unmatched constraint 'spi_cs' (on line 4)
Warning: unmatched constraint 'data[0]' (on line 6)
Warning: unmatched constraint 'data[1]' (on line 7)
Warning: unmatched constraint 'data[2]' (on line 8)
Warning: unmatched constraint 'data[3]' (on line 9)
Warning: unmatched constraint 'data[4]' (on line 10)
Warning: unmatched constraint 'data[5]' (on line 11)
Warning: unmatched constraint 'data[6]' (on line 12)
Warning: unmatched constraint 'data[7]' (on line 13)
Warning: unmatched constraint 'phi2' (on line 33)
Warning: unmatched constraint 'rwbar' (on line 34)
Warning: unmatched constraint 'dataoutenable' (on line 36)
Warning: unmatched constraint 'busenable' (on line 37)
Warning: unmatched constraint 'diag_spi_cs' (on line 39)
Warning: unmatched constraint 'rdy' (on line 40)
Warning: unmatched constraint 'rst' (on line 41)
Warning: unmatched constraint 'led_blue' (on line 43)
ERROR: IO 'dataout[7]' is unconstrained in PCF (override this error with --pcf-allow-unconstrained)
ERROR: Loading PCF failed.
20 warnings, 2 errors
scons: *** [hardware.asc] Error 255
============================================= [ ERROR ] Took 9.53 seconds =============================================
make: *** [Makefile:130: bin/hardware_6502.bin] Fehler 2
pi@romulator:~/bf-romulator $
```

bitfixer, 2024-01-13:
Hi Frank,
Thanks for letting me know. Interesting, I haven't seen that error before.
First, could you check a couple of things: the version of apio currently
installed on the pi (apio --version)
Also, you may need to pull the latest from the bf-romulator repository,
depending on when you cloned it. I made some changes recently to update to
apio version 0.8.1 and changed a bit in the verilog.
Would you mind sending me your config files, so I can see if I can
reproduce the same error?
Let's start there and hopefully can get to the root of the issue. Thanks,
- Mike

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
sjlevy, 2025-01-09:
I just re-imaged my raspberry pi and went through the setup process for bf-romulator (hadn't used it in awhile)

I am getting the same error:
```
ERROR: IO 'dataout[7]' is unconstrained in PCF (override this error with --pcf-allow-unconstrained)
```

With my old pi setup it seemed to work fine with apio 0.5.4, but now it does not seem to work with 0.8.1

I am using the latest master copy from github

Was there some change in apio syntax/strictness (starting with the use of 0.8.1) that is now failing in up5k.pcf?

I have tried various tricks such as adding
```
[build]
flags = --pcf-allow-unconstrained
```
to apio.ini to no avail, as well as some declarations and assignments for port 7 to try to force it through-- but I have no experience with HDL and none of that seemed to work either

This is my console dump:

```
~/bf-romulator $ make program
gpio mode 27 out
gpio write 27 1
gpio mode 6 out
gpio mode 10 out
bin/programmer -b
mkdir -p bin
cd romulator; rm -f input*.v; rm -f *.pcf
cp romulator/6502/* romulator
cd romulator; rm -f hardware.*; apio build
(DEBUG) Profile path: /home/pi/.apio/profile.json
(DEBUG) Home_dir: /home/pi/.apio

PATH: /home/pi/.apio/packages/tools-oss-cad-suite/bin:/home/pi/.apio/packages/tools-oss-cad-suite/lib:/home/pi/.apio/packages/toolchain-ice40/bin:/home/pi/.apio/packages/toolchain-yosys/bin:/home/pi/.apio/packages/tool-scons/script:/home/pi/.local/bin:/usr/local/sbin:/usr/local/bin:/usr/sbin:/usr/bin:/sbin:/bin:/usr/local/games:/usr/games:/home/pi/.local/bin:/home/pi/.local/bin

[Wed Jan  8 20:40:24 2025] Processing upduino
----------------------------------------------------------------------------------------------------------------------------------------------------------------------------------------
yosys -p "synth_ice40 -json hardware.json" -q SPI_Master.v diagnostics.v enable_logic.v input6502.v ramenable.v simple_ram_dual_clock.v spi_flash_reader.v spi_slave.v sram.v sram64k.v
Warning: Yosys has only limited support for tri-state logic at the moment. (spi_slave.v:197)
Warning: Resizing cell port sram.ramfn_inst1.POWEROFF from 32 bits to 1 bits.
Warning: Resizing cell port sram.ramfn_inst1.SLEEP from 32 bits to 1 bits.
Warning: Resizing cell port sram.ramfn_inst1.STANDBY from 32 bits to 1 bits.
nextpnr-ice40 --up5k --package sg48 --json hardware.json --asc hardware.asc --pcf up5k.pcf -q
Warning: unmatched constraint 'spi_clk' (on line 1)
Warning: unmatched constraint 'spi_miso' (on line 2)
Warning: unmatched constraint 'spi_out' (on line 3)
Warning: unmatched constraint 'spi_cs' (on line 4)
Warning: unmatched constraint 'data[0]' (on line 6)
Warning: unmatched constraint 'data[1]' (on line 7)
Warning: unmatched constraint 'data[2]' (on line 8)
Warning: unmatched constraint 'data[3]' (on line 9)
Warning: unmatched constraint 'data[4]' (on line 10)
Warning: unmatched constraint 'data[5]' (on line 11)
Warning: unmatched constraint 'data[6]' (on line 12)
Warning: unmatched constraint 'data[7]' (on line 13)
Warning: unmatched constraint 'phi2' (on line 33)
Warning: unmatched constraint 'rwbar' (on line 34)
Warning: unmatched constraint 'dataoutenable' (on line 36)
Warning: unmatched constraint 'dataoutenable' (on line 37)
Warning: unmatched constraint 'busenable' (on line 38)
Warning: unmatched constraint 'diag_spi_cs' (on line 40)
Warning: unmatched constraint 'rdy' (on line 41)
Warning: unmatched constraint 'rst' (on line 42)
Warning: unmatched constraint 'led_blue' (on line 44)
ERROR: IO 'dataout[7]' is unconstrained in PCF (override this error with --pcf-allow-unconstrained)
ERROR: Loading PCF failed.
21 warnings, 2 errors
scons: *** [hardware.asc] Error 255
```

If you can take another look at this I would appreciate it, let me know if there is any further testing I can do

Thank you

sjlevy, 2025-02-06:
Finally figured out how to get the current branch to compile

You need to roll back to apio 0.5.4

However, you also need to use the older version of Python because apio 0.5.4 will not work with Python versions > 3.9

Things can get hairy with OS-level global python on the latest Linux releases, so it's best to set up a pyenv for the /bf-romulator directory for python 3.9.18

The gist of it is:
1. Do the normal git clone and execute the setup.sh to get into the mostly non-functioning state
2. Install pyenv
3. Use pyenv to install 3.9.18 (note this may require some system-wide dependencies to successfully compile and install)
4. Activate a pyenv local environment in the bf-romulator directory and specify the local python version as 3.9.18
5. Assume control of the environment in that folder: python -m venv venv
6. pip install apio==0.5.4
7. apio install scons yosys ice40
8. Then finally 'make program'

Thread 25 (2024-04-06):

Adressdecoding for Commodore 1541 Floppy Drive

FraEgg, 2024-04-06:
Hello Michael,

I used your great Romulator 6502 in my Commodore 1541 floppy drive. I can now use many floppy speeders like DolphinDos etc. with it. However, there is a small improvement for your Romulator in a 1541 floppy drive. The IO ICs VIA are at address $1800 and $1C00 and are mirrored by the simple address decoding every 2K in the address space. This has the disadvantage that with the romulator from $2000 - $7FFF I cannot provide any additional memory through the romulator, as the VIAs then interfere with write accesses /WE. But I have found a solution. If you set the A15 on the mainboard address bus to high, then the VIAs no longer interfere and I can insert additional RAM from $2000-$BFFF. Then DOS and KERNAL appear. Maybe that would be a feature for the Romulator. I have an intermediate board running at the moment. But I think that something like this can also be built into the Romulator as a feature.

Logic:
Stop VIAs Mirroring on 1541 Floppydrive
                         ------
CPU A15----+        |
CPU A14----+ OR + ----A15 Mainboard 1541 Floppydrive
CPU A13----+        |
                        -------

Greetings from Berlin
Frank

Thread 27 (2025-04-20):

unable to install tools-oss-cad

coopzone-dc, 2025-04-20:
In preparation for using the romulator I am trying to install the software on a raspberry pi 3b. It looks like the oss-cad-suite package is no longer available, I checked the github page and it really is not listed!

pi@raspberrypi:~/bf-romulator$ apio install -a
(DEBUG) Profile path: /home/pi/.apio/profile.json
(DEBUG) Home_dir: /home/pi/.apio
Installing examples package:
Already installed. Version 0.0.36
(DEBUG) Profile path: /home/pi/.apio/profile.json
(DEBUG) Home_dir: /home/pi/.apio
Installing oss-cad-suite package:
Warning: full platform does not match: linux_armv7l
         Trying OS name: linux
Error: Got an unrecognized status code '404' when downloaded https://github.com/FPGAwars/tools-oss-cad-suite/releases/download/v0.2.1/tools-oss-cad-suite-linux-0.2.1.tar.gz

As a work-a-round I have installed the system on an Ubuntu 22.04 system, created the image on it and transferred it to the Pi ready to attempt to program the romulator, we shall see.

Thanks

Derek

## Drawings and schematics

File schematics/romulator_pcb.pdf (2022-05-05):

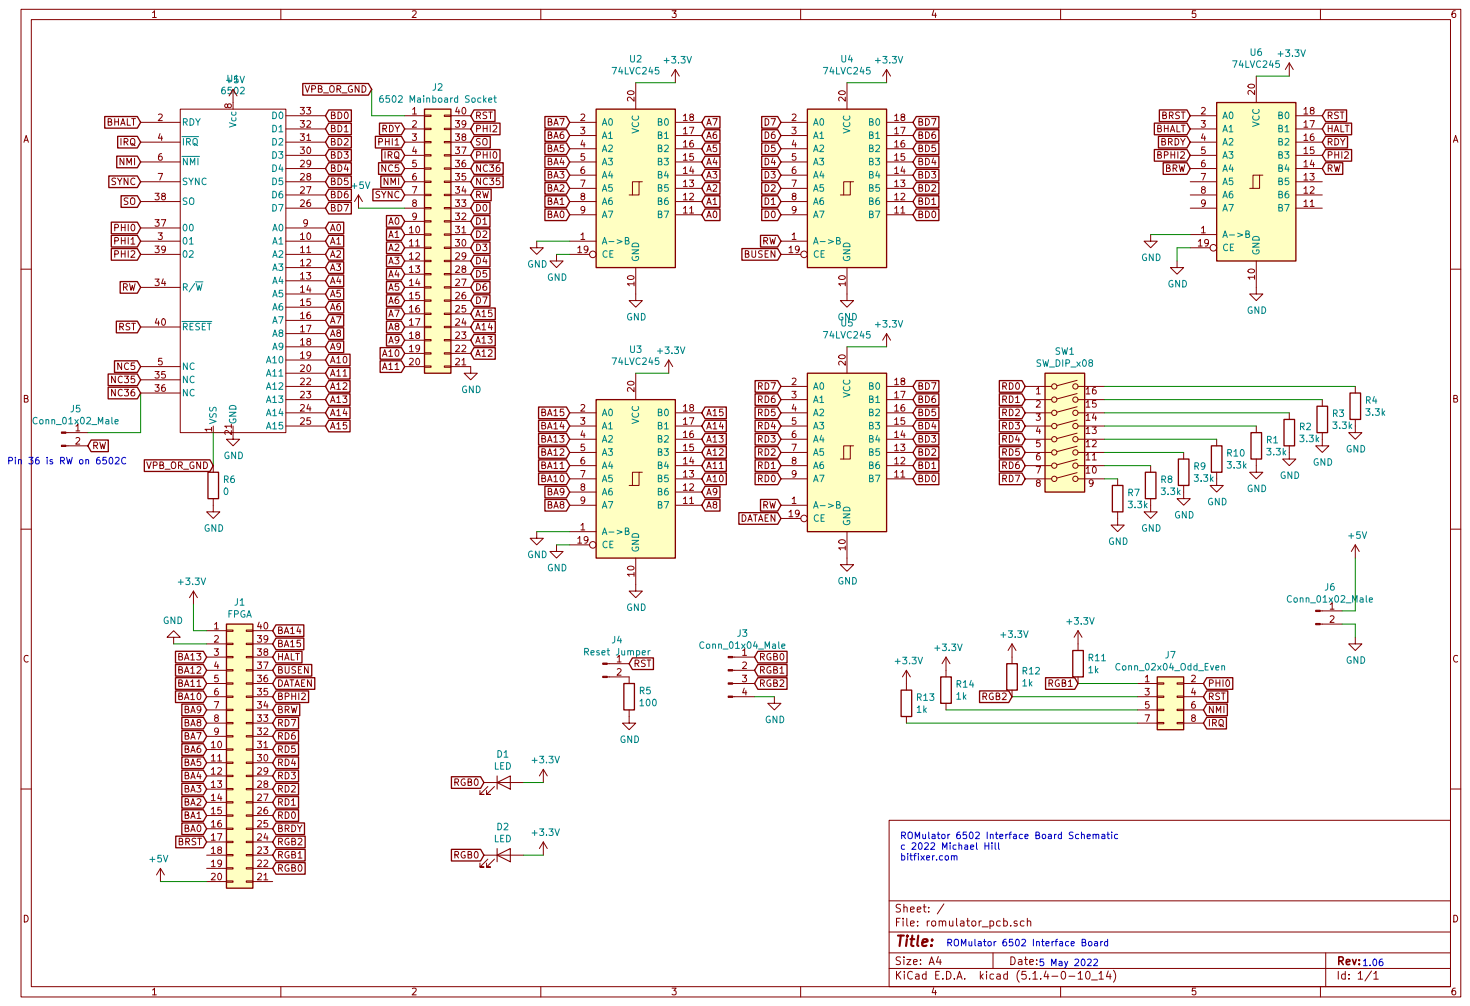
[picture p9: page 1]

File: romulator_pcb.sch Sheet: / VSS

ROMulator 6502 Interface Board Schematic
c 2022 Michael Hill bitfixer.com

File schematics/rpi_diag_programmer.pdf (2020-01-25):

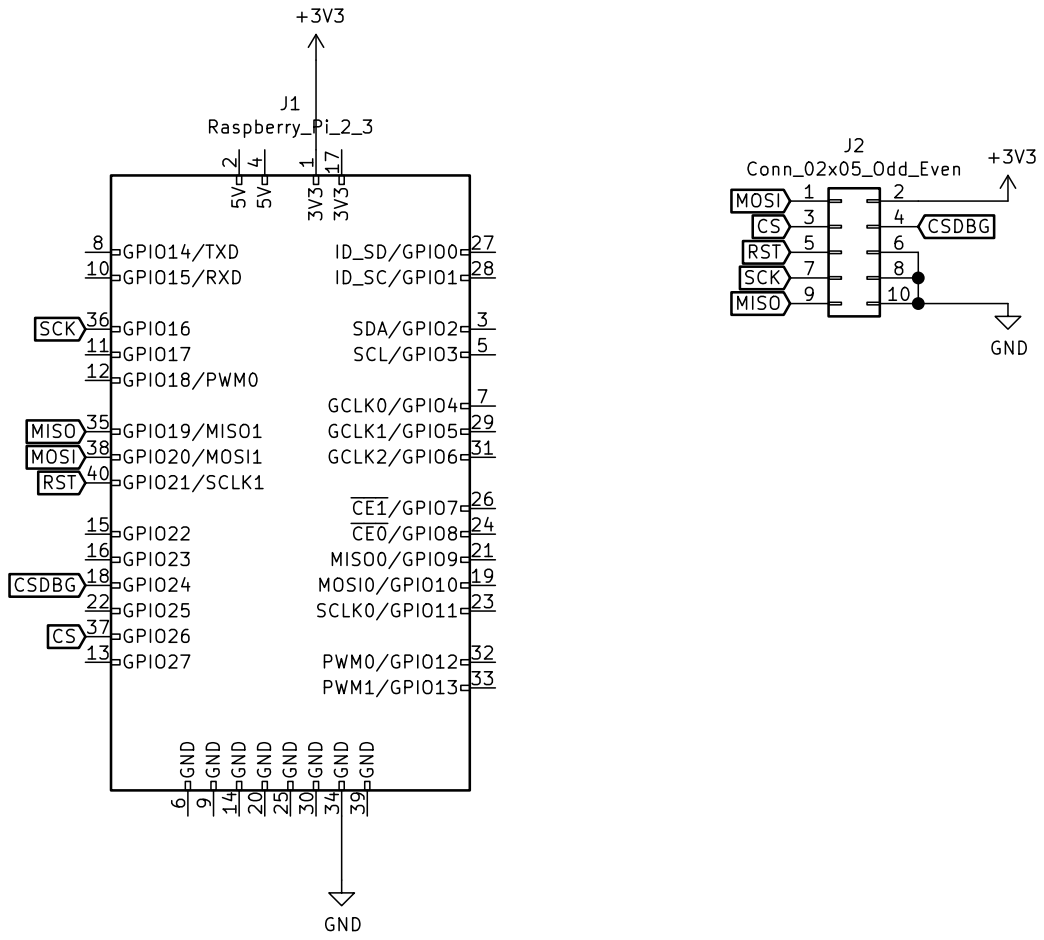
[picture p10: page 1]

1 GPIO15/RXD 10 GPIO17 11 GPIO18/PWM0 12 GPIO27 13 GND 14 GPIO22 15 GPIO23 16 3V3 17 GPIO24 18 MOSI0/GPIO10 19 5V
CSDBG MISO
SCK MOSI RST CSDBG

ROMulator Raspberry Pi Programming/Diagnostic Interface.
Connects to 40-pin RPI GPIO header.
Brings out a 10 pin SPI programming header.
Also serves as a debug interface with console program.

ROMulator RPI Programming/Diagnostic Interface

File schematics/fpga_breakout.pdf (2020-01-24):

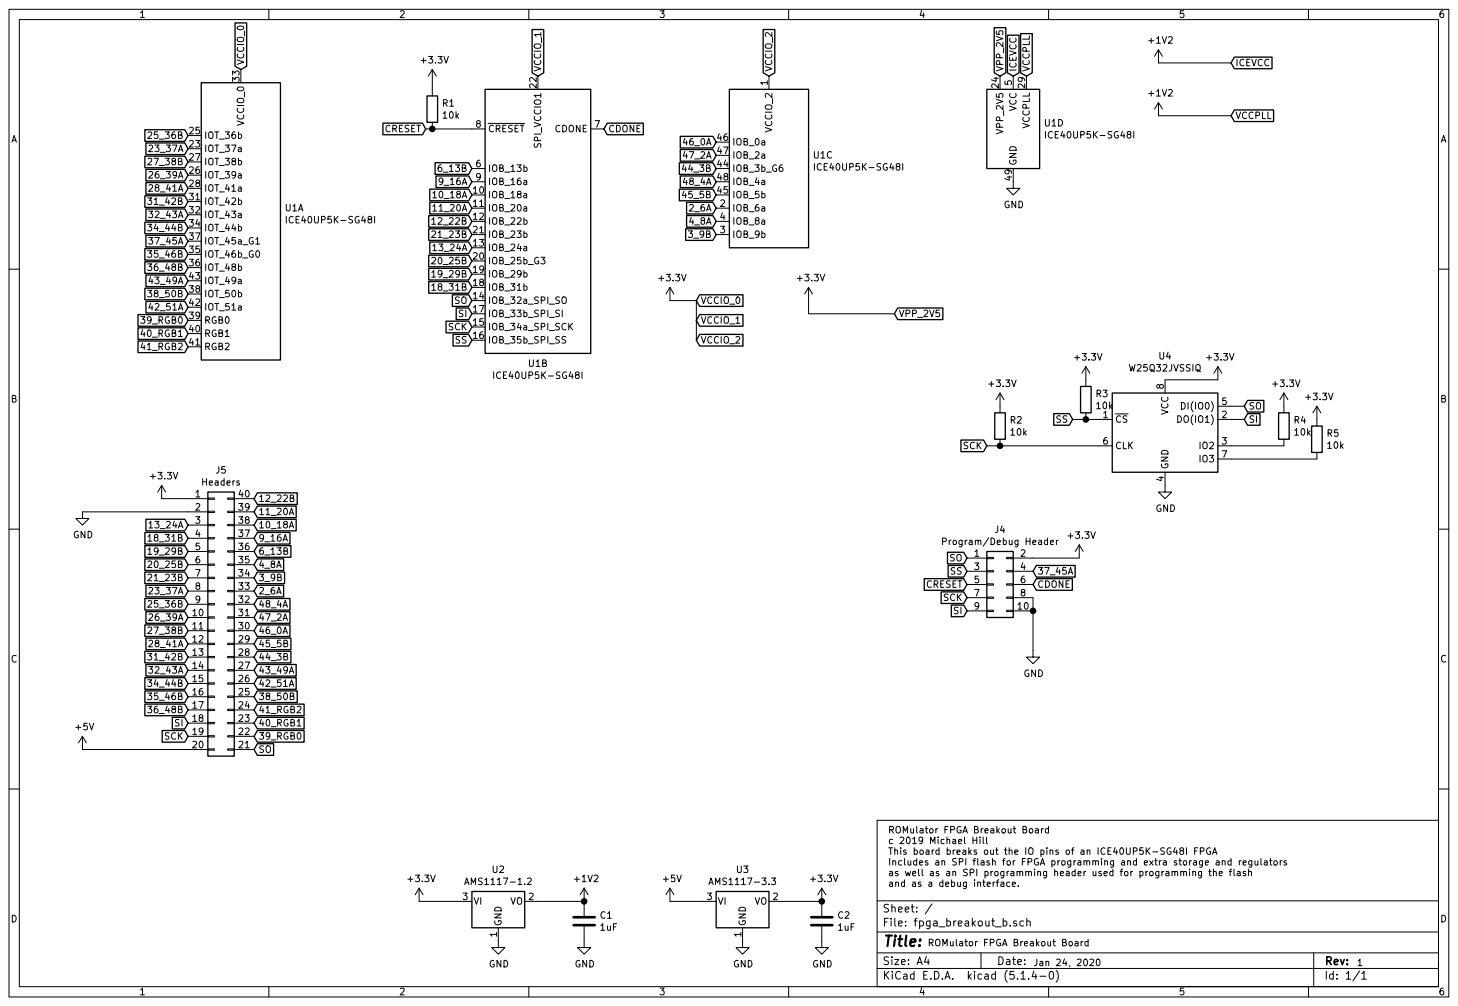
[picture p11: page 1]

1 ROMulator FPGA Breakout Board ROMulator FPGA Breakout Board
c 2019 Michael Hill This board breaks out the IO pins of an ICE40UP5K-SG48I FPGA

Includes an SPI flash for FPGA programming and extra storage and regulators
as well as an SPI programming header used for programming the flash
File: fpga_breakout_b.sch Sheet: /
Id: 1/1 Title:

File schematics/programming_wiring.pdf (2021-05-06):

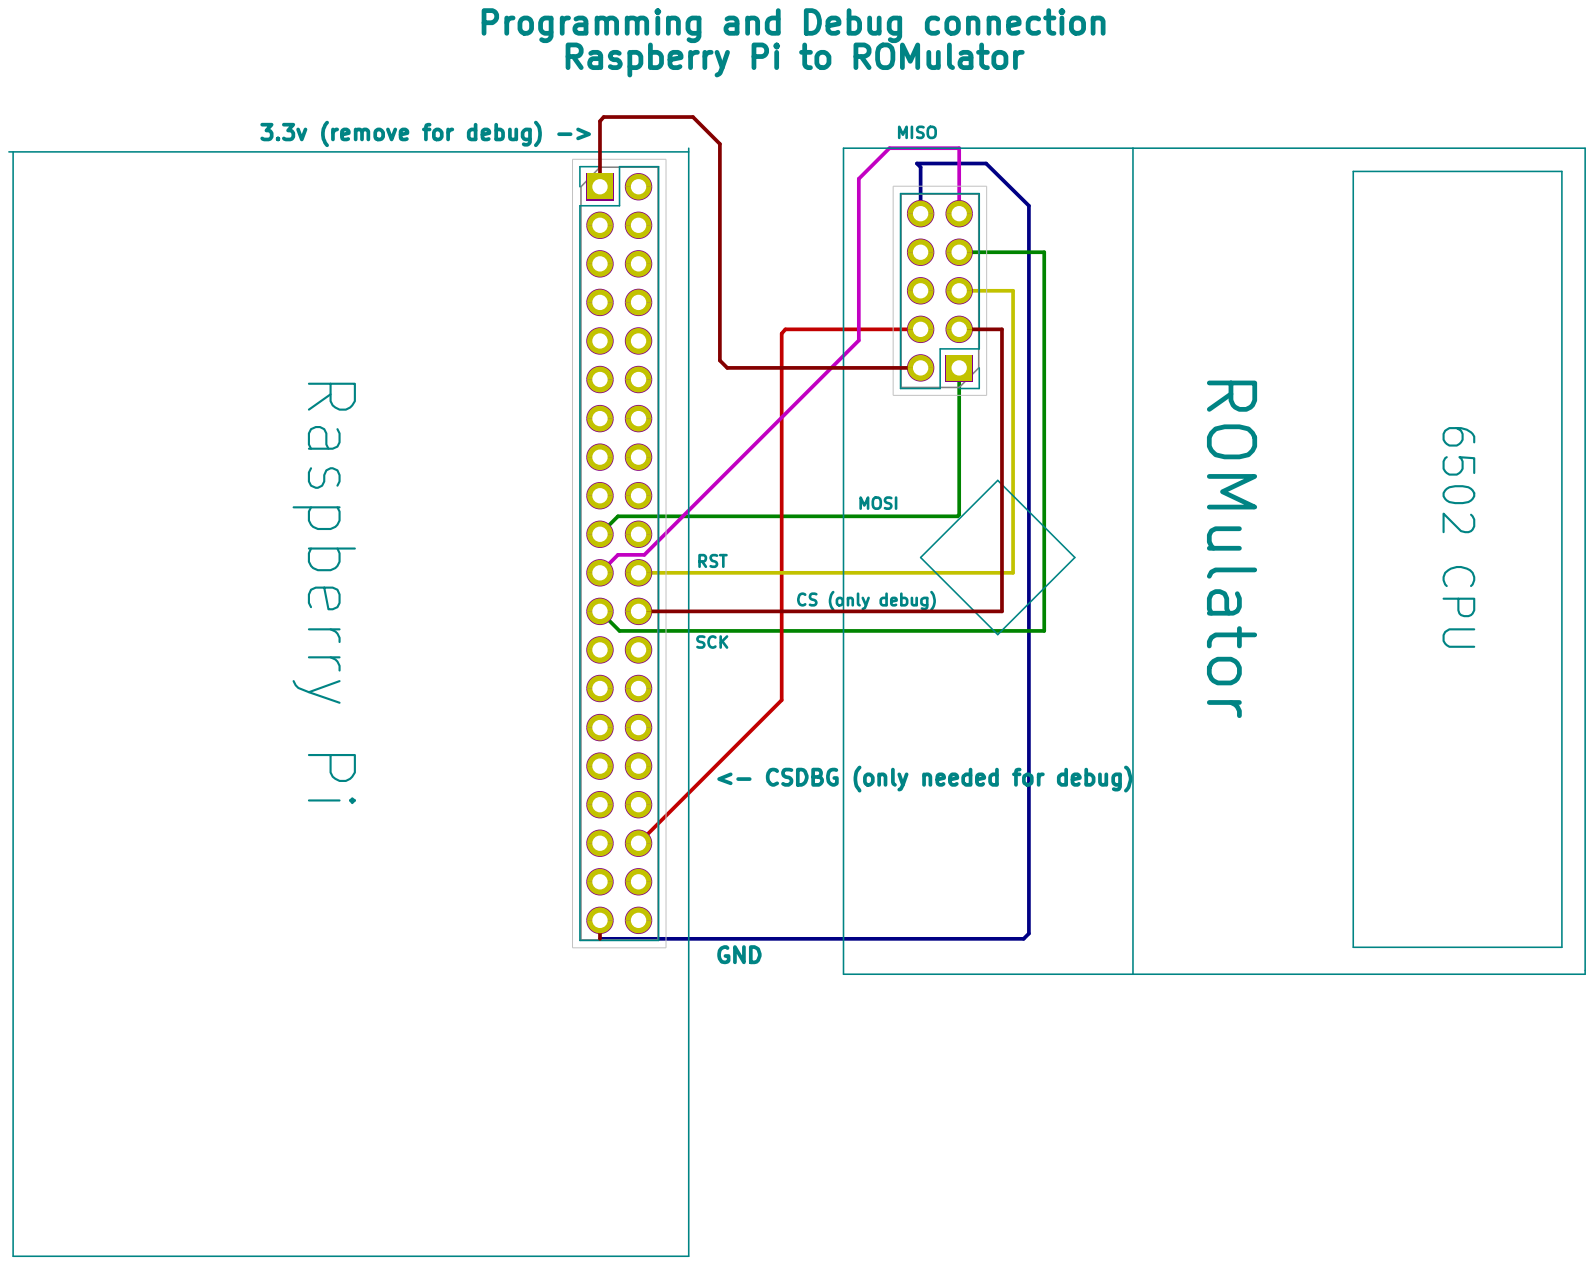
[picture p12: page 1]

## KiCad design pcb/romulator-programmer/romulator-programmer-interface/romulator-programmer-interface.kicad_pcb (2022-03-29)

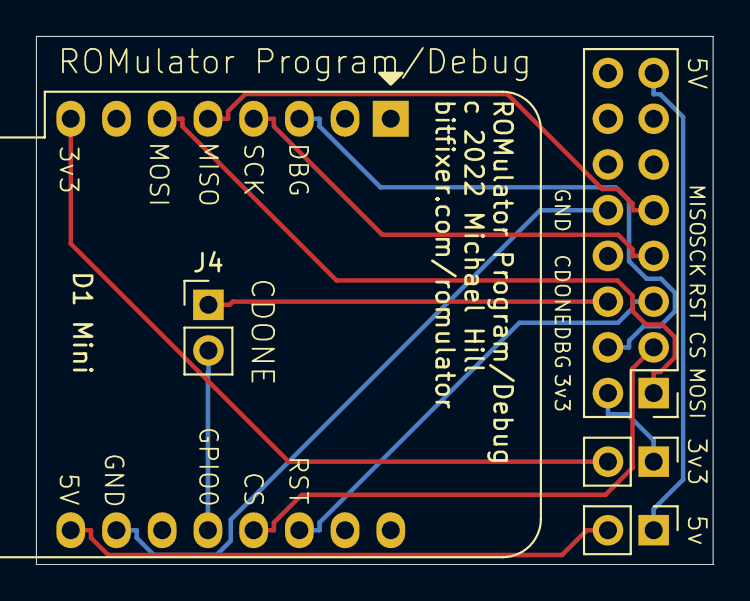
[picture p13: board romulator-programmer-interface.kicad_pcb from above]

Board: 2 copper layers, 37.6 x 29.3 mm, 5 parts (0 on the bottom side), 13 nets.

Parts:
J1, J2, J4: Conn_01x02_Male; PinHeader_1x02_P2.54mm_Vertical
J3: Conn_02x08_Odd_Even; PinHeader_2x08_P2.54mm_Vertical
U1: WeMos_D1_mini; WEMOS_D1_mini_light

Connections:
3v3IN: J1.2, U1.8
5VIN: J2.2, U1.9
+3V3: J1.1, J3.2
+5V: J2.1, J3.15
CDONE: J3.6, J4.1
CS: J3.3, U1.13
DBG: J3.4, U1.3
GND: J3.10, U1.10
GPIO0: J4.2, U1.12
MISO: J3.9, U1.5
MOSI: J3.1, U1.6
RST: J3.5, U1.14
SCK: J3.7, U1.4

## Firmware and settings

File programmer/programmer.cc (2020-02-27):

// ROMulator - RAM/ROM replacement and diagnostic for 8-bit CPUs
// Copyright (C) 2019  Michael Hill

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
// programmer.cc - programmer to update flash contents on ROMulator FPGA board

#include <time.h>
#include <stdio.h>
#include <stdlib.h>
#include <stdint.h>
#include <string.h>
#include <unistd.h>
#include <termios.h>
#include <assert.h>
#include <vector>

#define PI_ICE_MISO       13
#define PI_ICE_CLK        14
#define PI_ICE_CDONE      0

#define PI_ICE_CRESET     6
#define PI_ICE_MOSI       12
#define PI_ICE_CS         10

using namespace std;
#include <wiringPi.h>

bool verbose = false;
bool ftdi_verbose = false;

bool send_zero = false;
bool recv_zero = false;
char current_send_recv_mode = 0;
int current_recv_ep = -1;

int last_recv_v = -1;
int last_recv_rep = 0;

void fpga_reset()
{
    pinMode(PI_ICE_CRESET,  OUTPUT);
    digitalWrite(PI_ICE_CRESET, LOW);
    delayMicroseconds(2000);
    digitalWrite(PI_ICE_CRESET, HIGH);
    delayMicroseconds(500000);
    if (digitalRead(PI_ICE_CDONE) != HIGH)
        fprintf(stderr, "Warning: cdone is low\n");
}

int get_time_ms()
{
    static struct timespec spec_start;
    static bool spec_start_initialized = false;
    
    struct timespec spec_now;
    clock_gettime(CLOCK_REALTIME, &spec_now);
    if (!spec_start_initialized) {
        spec_start = spec_now;
        spec_start_initialized = true;
    }
    
    int s = spec_now.tv_sec - spec_start.tv_sec;
    int ns = spec_now.tv_nsec - spec_start.tv_nsec;
    
    return s*1000 + ns/1000000;
}

void prog_bitstream(bool reset_only = false)
{
    pinMode(PI_ICE_CLK,     OUTPUT);
    pinMode(PI_ICE_MISO,    OUTPUT);
    pinMode(PI_ICE_CRESET,  OUTPUT);
    pinMode(PI_ICE_CS,      OUTPUT);
    
    fprintf(stderr, "reset..\n");
    
    // enable reset
    digitalWrite(PI_ICE_CRESET, LOW);
    
    // start clock high
    digitalWrite(PI_ICE_CLK, HIGH);
    
    // select SRAM programming mode
    digitalWrite(PI_ICE_CS, LOW);
    delayMicroseconds(100);
    
    // release reset
    digitalWrite(PI_ICE_CRESET, HIGH);
    delayMicroseconds(2000);
    
    //fprintf(stderr, "cdone: %s\n", digitalRead(PI_ICE_CDONE) == HIGH ? "high" : "low");
    
    if (reset_only)
        return;
    
    fprintf(stderr, "programming..\n");
    
    while (1)
    {
        int byte = getchar();
        if (byte < 0)
            break;
        for (int i = 7; i >= 0; i--) {
            digitalWrite(PI_ICE_MISO, ((byte >> i) & 1) ? HIGH : LOW);
            digitalWrite(PI_ICE_CLK, LOW);
            digitalWrite(PI_ICE_CLK, HIGH);
        }
    }
    
    for (int i = 0; i < 49; i++) {
        digitalWrite(PI_ICE_CLK, LOW);
        digitalWrite(PI_ICE_CLK, HIGH);
    }
    
    delayMicroseconds(2000);
    
    fprintf(stderr, "cdone: %s\n", digitalRead(PI_ICE_CDONE) == HIGH ? "high" : "low");
}

void spi_begin()
{
    digitalWrite(PI_ICE_CS, LOW);
}

void spi_end()
{
    digitalWrite(PI_ICE_CS, HIGH);
}

uint32_t spi_xfer(uint32_t data, int nbits = 8)
{
    uint32_t rdata = 0;
    
    for (int i = nbits-1; i >= 0; i--)
    {
        digitalWrite(PI_ICE_MOSI, (data & (1 << i)) ? HIGH : LOW);
        
        if (digitalRead(PI_ICE_MISO) == HIGH)
            rdata |= 1 << i;
        
        digitalWrite(PI_ICE_CLK, HIGH);
        digitalWrite(PI_ICE_CLK, LOW);
    }
    
    return rdata;
}

uint32_t spi_xfer_slow(uint32_t data, int nbits = 8)
{
    uint32_t rdata = 0;
    
    for (int i = nbits-1; i >= 0; i--)
    {
        digitalWrite(PI_ICE_MOSI, (data & (1 << i)) ? HIGH : LOW);
        
        delayMicroseconds(1);   
        if (digitalRead(PI_ICE_MISO) == HIGH)
            rdata |= 1 << i;
        
        delayMicroseconds(1);
        digitalWrite(PI_ICE_CLK, HIGH);
        delayMicroseconds(1);
        digitalWrite(PI_ICE_CLK, LOW);
        delayMicroseconds(1);
    }
    
    return rdata;
}

void flash_write_enable()
{
    spi_begin();
    spi_xfer(0x06);
    spi_end();
}

void flash_bulk_erase()
{
    spi_begin();
    spi_xfer(0xc7);
    spi_end();
}

void flash_erase_64kB(int addr)
{
    spi_begin();
    spi_xfer(0xd8);
    spi_xfer(addr >> 16);
    spi_xfer(addr >> 8);
    spi_xfer(addr);
    spi_end();
}

void flash_write(int addr, uint8_t *data, int n)
{
    spi_begin();
    spi_xfer(0x02);
    spi_xfer(addr >> 16);
    spi_xfer(addr >> 8);
    spi_xfer(addr);
    while (n--)
        spi_xfer(*(data++));
    spi_end();
}

void flash_read(int addr, uint8_t *data, int n)
{
    spi_begin();
    spi_xfer(0x03);
    spi_xfer(addr >> 16);
    spi_xfer(addr >> 8);
    spi_xfer(addr);
    while (n--)
        *(data++) = spi_xfer(0);
    spi_end();
}

void flash_read_slow(int addr, uint8_t *data, int n)
{
    spi_begin();
    spi_xfer_slow(0x03);
    spi_xfer_slow(addr >> 16);
    spi_xfer_slow(addr >> 8);
    spi_xfer_slow(addr);
    while (n--)
        *(data++) = spi_xfer_slow(0);
    spi_end();
}

int flash_wait()
{
    int ms_start = get_time_ms();
    
    while (1)
    {
        spi_begin();
        spi_xfer(0x05);
        int status = spi_xfer(0);
        spi_end();
        
        if ((status & 0x01) == 0)
            break;
        
        delayMicroseconds(1000);
    }
    
    return get_time_ms() - ms_start;
}

void prog_flasherase()
{
    pinMode(PI_ICE_CLK,     OUTPUT);
    pinMode(PI_ICE_MOSI,    OUTPUT);
    pinMode(PI_ICE_CS,      OUTPUT);
    
    // connect flash to Raspi
    digitalWrite(PI_ICE_CS, HIGH);
    digitalWrite(PI_ICE_CLK, LOW);
    delayMicroseconds(100);
    
    // power_up
    spi_begin();
    spi_xfer(0xab);
    spi_end();
    
    flash_write_enable();
    flash_bulk_erase();
    
    // power_down
    spi_begin();
    spi_xfer(0xb9);
    spi_end();
}

void prog_flashmem(int pageoffset)
{
    pinMode(PI_ICE_CLK,     OUTPUT);
    pinMode(PI_ICE_MOSI,    OUTPUT);
    pinMode(PI_ICE_CS,      OUTPUT);
    
    // connect flash to Raspi
    digitalWrite(PI_ICE_CS, HIGH);
    digitalWrite(PI_ICE_CLK, LOW);
    delayMicroseconds(100);
    
    // power_up
    spi_begin();
    spi_xfer(0xab);
    spi_end();
    
    // read flash id
    spi_begin();
    spi_xfer(0x9f);
    fprintf(stderr, "flash id:");
    for (int i = 0; i < 20; i++)
        fprintf(stderr, " %02x", spi_xfer(0x00));
    fprintf(stderr, "\n");
    spi_end();
    
    // load prog data into buffer
    std::vector<uint8_t> prog_data;
    while (1) {
        int byte = getchar();
        if (byte < 0)
            break;
        prog_data.push_back(byte);
    }
    
    int ms_timer = 0;
    fprintf(stderr, "writing %.2fkB..", double(prog_data.size()) / 1024);
    
    for (int addr = 0; addr < int(prog_data.size()); addr += 256)
    {
        if (addr % (64*1024) == 0)
        {
            fprintf(stderr, "\n%3d%% @%06x ", 100*addr/int(prog_data.size()), addr);
            fprintf(stderr, "erasing 64kB sector..");
            
            flash_write_enable();
            flash_erase_64kB(addr + pageoffset * 0x10000);
            ms_timer += flash_wait();
        }
        
        if (addr % (32*256) == 0) {
            fprintf(stderr, "\n%3d%% @%06x writing: ", 100*addr/int(prog_data.size()), addr);
        }
        
        int n = std::min(256, int(prog_data.size()) - addr);
        uint8_t buffer[256];
        
        for (int retry_count = 0; retry_count < 100; retry_count++)
        {
            flash_write_enable();
            flash_write(addr + pageoffset * 0x10000, &prog_data[addr], n);
            ms_timer += flash_wait();
            
            flash_read(addr + pageoffset * 0x10000, buffer, n);
            
            if (!memcmp(buffer, &prog_data[addr], n)) {
                fprintf(stderr, "o");
                goto written_ok;
            }
            
            fprintf(stderr, "X");
        }
        
        // restart erasing and writing this 64kB sector
        addr -= addr % (64*1024);
        addr -= 256;
        
    written_ok:;
    }
    
    fprintf(stderr, "\n100%% total wait time: %d ms\n", ms_timer);
    
    // power_down
    spi_begin();
    spi_xfer(0xb9);
    spi_end();
}

void ice_reset()
{
    pinMode(PI_ICE_CRESET,      OUTPUT);
    digitalWrite(PI_ICE_CRESET, LOW);
}

void read_flashmem(int n)
{
    pinMode(PI_ICE_CLK,     OUTPUT);
    pinMode(PI_ICE_MOSI,    OUTPUT);
    pinMode(PI_ICE_CS,      OUTPUT);
    
    // connect flash to Raspi
    digitalWrite(PI_ICE_CS, HIGH);
    digitalWrite(PI_ICE_CLK, LOW);
    delayMicroseconds(100);
    
    // power_up
    spi_begin();
    spi_xfer(0xab);
    spi_end();
    
    // read flash id
    spi_begin();
    spi_xfer(0x9f);
    fprintf(stderr, "flash id:");
    for (int i = 0; i < 20; i++)
        fprintf(stderr, " %02x", spi_xfer(0x00));
    fprintf(stderr, "\n");
    spi_end();
    
    fprintf(stderr, "reading %.2fkB..\n", double(n) / 1024);
    for (int addr = 0; addr < n; addr += 256) {
        uint8_t buffer[256];
        fprintf(stderr, "%d\t%X\n", addr, addr);
        flash_read_slow(addr, buffer, std::min(256, n - addr));
        fwrite(buffer, std::min(256, n - addr), 1, stdout);
    }
    
    // power_down
    spi_begin();
    spi_xfer(0xb9);
    spi_end();
}

void reset_inout()
{
    pinMode(PI_ICE_CLK,     INPUT);
    pinMode(PI_ICE_CDONE,   INPUT);
    pinMode(PI_ICE_MOSI,    INPUT);
    pinMode(PI_ICE_MISO,    INPUT);
    pinMode(PI_ICE_CRESET,  INPUT);
    pinMode(PI_ICE_CS,      INPUT);
    
    current_send_recv_mode = 0;
}

void help(const char *progname)
{
    fprintf(stderr, "\n");
    fprintf(stderr, "Resetting FPGA:\n");
    fprintf(stderr, "    %s -R\n", progname);
    fprintf(stderr, "\n");
    fprintf(stderr, "Resetting FPGA (reload from flash):\n");
    fprintf(stderr, "    %s -b\n", progname);
    fprintf(stderr, "\n");
    fprintf(stderr, "Bulk erase entire flash:\n");
    fprintf(stderr, "    %s -E\n", progname);
    fprintf(stderr, "\n");
    fprintf(stderr, "Programming FPGA bit stream:\n");
    fprintf(stderr, "    %s -p < data.bin\n", progname);
    fprintf(stderr, "\n");
    fprintf(stderr, "Programming serial flash:\n");
    fprintf(stderr, "    %s -f < data.bin\n", progname);
    fprintf(stderr, "\n");
    fprintf(stderr, "Reading serial flash (first N bytes):\n");
    fprintf(stderr, "    %s -F N > data.bin\n", progname);
    fprintf(stderr, "\n");
    fprintf(stderr, "Testing bit-parallel link (using ep0):\n");
    fprintf(stderr, "    %s -T\n", progname);
    fprintf(stderr, "\n");
    fprintf(stderr, "Testing link bandwidth (using ep0):\n");
    fprintf(stderr, "    %s -B\n", progname);
    fprintf(stderr, "\n");
    fprintf(stderr, "Writing a file to ep N:\n");
    fprintf(stderr, "    %s -w N < data.bin\n", progname);
    fprintf(stderr, "\n");
    fprintf(stderr, "Reading a file from ep N:\n");
    fprintf(stderr, "    %s -r N > data.bin\n", progname);
    fprintf(stderr, "\n");
    fprintf(stderr, "Console at ep N:\n");
    fprintf(stderr, "    %s -c N\n", progname);
    fprintf(stderr, "\n");
    fprintf(stderr, "Dumping a VCD file (from ep1, using trig1)\n");
    fprintf(stderr, "  with a debug core with N bits width:\n");
    fprintf(stderr, "    %s -V N > dbg_trace.vcd\n", progname);
    fprintf(stderr, "\n");
    fprintf(stderr, "Additional options:\n");
    fprintf(stderr, "    -v      verbose output\n");
    fprintf(stderr, "    -O N    offset (in 64 kB pages) for -f\n");
    fprintf(stderr, "    -z      send a terminating zero byte with -w/-c\n");
    fprintf(stderr, "    -Z      wait for terminating zero byte in -r/-c\n");
    fprintf(stderr, "    -t N    send trigger N before -w/-r/-c\n");
    fprintf(stderr, "\n");
    exit(1);
}

int main(int argc, char **argv)
{
    int opt, n = -1, t = -1;
    int pageoffset = 0;
    char mode = 0;
    
    while ((opt = getopt(argc, argv, "RbEpfF:TBw:r:c:vzZt:O:V:")) != -1)
    {
        switch (opt)
        {
            case 'w':
            case 'r':
            case 'c':
            case 'V':
            case 'F':
                n = atoi(optarg);
                // fall through
                
            case 'E':
            case 'R':
            case 'b':
            case 'p':
            case 'f':
            case 'T':
            case 'B':
                if (mode)
                    help(argv[0]);
                mode = opt;
                break;
                
            case 'v':
                if (verbose)
                    ftdi_verbose = true;
                verbose = true;
                break;
                
            case 'z':
                send_zero = true;
                break;
                
            case 'Z':
                recv_zero = true;
                break;
                
            case 't':
                t = atoi(optarg);
                break;
                
            case 'O':
                pageoffset = atoi(optarg);
                break;
                
            default:
                help(argv[0]);
        }
    }
    
    if (optind != argc || !mode)
        help(argv[0]);
    
    if (mode == 'R') {
        wiringPiSetup();
        reset_inout();
        prog_bitstream(true);
        reset_inout();
    }
    
    if (mode == 'b') {
        wiringPiSetup();
        reset_inout();
        fpga_reset();
        reset_inout();
    }
    
    if (mode == 'E') {
        wiringPiSetup();
        reset_inout();
        prog_flasherase();
        reset_inout();
    }
    
    if (mode == 'p') {
        wiringPiSetup();
        reset_inout();
        prog_bitstream();
        reset_inout();
    }
    
    if (mode == 'f') {
        wiringPiSetup();
        reset_inout();
        ice_reset();
        prog_flashmem(pageoffset);
        reset_inout();
    }
    
    if (mode == 'F') {
        wiringPiSetup();
        reset_inout();
        ice_reset();
        read_flashmem(n);
        reset_inout();
    }
    
    if (verbose)
        fprintf(stderr, "\n");
    
    return 0;
}

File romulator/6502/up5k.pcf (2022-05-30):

set_io --warn-no-port spi_clk 15
set_io --warn-no-port spi_miso 17
set_io --warn-no-port spi_out 14
set_io --warn-no-port spi_cs 16

set_io --warn-no-port data[0] 42
set_io --warn-no-port data[1] 43
set_io --warn-no-port data[2] 44
set_io --warn-no-port data[3] 45
set_io --warn-no-port data[4] 46
set_io --warn-no-port data[5] 47
set_io --warn-no-port data[6] 48
set_io --warn-no-port data[7] 2

set_io --warn-no-port address[0] 35
set_io --warn-no-port address[1] 34
set_io --warn-no-port address[2] 32
set_io --warn-no-port address[3] 31
set_io --warn-no-port address[4] 28
set_io --warn-no-port address[5] 27
set_io --warn-no-port address[6] 26
set_io --warn-no-port address[7] 25
set_io --warn-no-port address[8] 23
set_io --warn-no-port address[9] 21
set_io --warn-no-port address[10] 20
set_io --warn-no-port address[11] 19
set_io --warn-no-port address[12] 18
set_io --warn-no-port address[13] 13

set_io --warn-no-port address[14] 12
set_io --warn-no-port address[15] 11

set_io --warn-no-port phi2 4
set_io --warn-no-port rwbar 3

set_io --warn-no-port dataoutenable 6
set_io --warn-no-port busenable 9

set_io --warn-no-port diag_spi_cs 37
set_io --warn-no-port rdy 10
set_io --warn-no-port rst 36

set_io --warn-no-port led_blue 39

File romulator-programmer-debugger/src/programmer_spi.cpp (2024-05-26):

// ROMulator - RAM/ROM replacement and diagnostic for 8-bit CPUs
// Copyright (C) 2019  Michael Hill

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
// programmer_spi.cpp
// program FPGA board using hardware SPI on rpi

#include <stdio.h>
#include <stdint.h>
#include <string.h>
#include <stdlib.h>
#include <unistd.h>
#include "defines.h"
#include "libRomulatorDebug.h"
#include "libRomulatorProgrammer.h"
#include "rServer.h"
#include <vector>
#include <Arduino.h>
#include <SPI.h>
#include <LittleFS.h>
#include "xmodem.h"
#include <EEPROM.h>
#include <WiFiClient.h>
#include <ESP8266WebServer.h>

unsigned char _inBuffer[512];
typedef enum mode
{
    MENU,
    PROGRAMMING,
    DEBUG
} Mode;

typedef struct _settings {
    uint32_t baudrate;
} Settings;

Mode _mode;
bool _cpuHalted;
RomulatorProgrammer _programmer;
int _lastInputMillis;

int get_time_ms()
{
    return millis();
}

void wiringPiSPIDataRW(int channel, unsigned char* data, int len)
{
    digitalWrite(PI_ICE_CS, 0);
    SPI.transferBytes(data, _inBuffer, len);
    memcpy(data, _inBuffer, len);
    digitalWrite(PI_ICE_CS, 1);
}

int flash_wait()
{
    int ms_start = get_time_ms();
    
    while (1)
    {
        uint8_t buffer[2];
        buffer[0] = 0x05;
        buffer[1] = 0;

        wiringPiSPIDataRW(0, buffer, 2);
        int status = buffer[1];

        if ((status & 0x01) == 0)
            break;
        
        delayMicroseconds(1000);
    }
    
    return get_time_ms() - ms_start;
}

void flash_erase_64kB(int addr)
{
    uint8_t buffer[4];
    buffer[0] = 0xd8;
    buffer[1] = addr >> 16;
    buffer[2] = addr >> 8;
    buffer[3] = addr;
    wiringPiSPIDataRW(0, buffer, 4);
}

void flash_write_enable()
{
    uint8_t cmd = 0x06;
    wiringPiSPIDataRW(0, &cmd, 1);
}

void flash_write(int addr, uint8_t *data, int n)
{
    uint8_t* buffer = new uint8_t[n + 4];
    memset(buffer, 0, n+4);
    buffer[0] = 0x02;
    buffer[1] = addr >> 16;
    buffer[2] = addr >> 8;
    buffer[3] = addr;

    memcpy(&buffer[4], data, n);
    wiringPiSPIDataRW(0, buffer, n+4);
    delete[] buffer;
}

void flash_read(int addr, uint8_t *data, int n)
{
    uint8_t* buffer = new uint8_t[n + 4];
    memset(buffer, 0, n+4);
    buffer[0] = 0x03;
    buffer[1] = addr >> 16;
    buffer[2] = addr >> 8;
    buffer[3] = addr;

    wiringPiSPIDataRW(0, buffer, n+4);
    memcpy(data, &buffer[4], n);
    delete[] buffer;
}

void power_up()
{
    uint8_t cmd = 0xab;
    wiringPiSPIDataRW(0, &cmd, 1);
}

void power_down()
{
    uint8_t cmd = 0xb9;
    wiringPiSPIDataRW(0, &cmd, 1);
}

void read_flash_id()
{
    uint8_t buffer[21];
    memset(buffer, 0, 21);
    buffer[0] = 0x9f;
    wiringPiSPIDataRW(0, buffer, 21);

    Serial.printf("flash id:");
    for (int i = 0; i < 20; i++)
        Serial.printf(" %02x", buffer[i]);
    Serial.printf("\r\n");
}

void read_flashmem(int n)
{
    Serial.printf("read flash mem, max size %d\r\n", n);
    // connect flash to Raspi
    delayMicroseconds(100);
    
    Serial.printf("power up\r\n");
    // power_up
    power_up();

    Serial.printf("read flash id\r\n");
    // read flash id
    read_flash_id();
    
    Serial.printf("reading %.2fkB..\r\n", double(n) / 1024);
    for (int addr = 0; addr < n; addr += 256) {
        uint8_t buffer[256];
        flash_read(addr, buffer, std::min(256, n - addr));
        //fwrite(buffer, std::min(256, n - addr), 1, stdout);

        for (int i = 0; i < 32; i++) {
            Serial.printf("%d: %X\r\n", addr+i, buffer[i]);
        }
    }
    
    // power_down
    power_down();
}

void prog_flashmem(int pageoffset)
{
    // first try to open data file
    File fp = LittleFS.open("/romulator.bin", "r");
    if (!fp)
    {
        Serial.printf("error: could not open romulator.bin\r\n");
        return;
    }

    delayMicroseconds(100);
    
    // power_up
    power_up();
    
    // read flash id
    read_flash_id();
    
    int ms_timer = 0;
    Serial.printf("writing %.2fkB..", double(fp.size()) / 1024);
    
    for (int addr = 0; addr < int(fp.size()); addr += 256)
    {
        if (addr % (64*1024) == 0)
        {
            Serial.printf("\n%3d%% @%06x ", 100*addr/int(fp.size()), addr);
            Serial.printf("erasing 64kB sector..");
            
            flash_write_enable();
            flash_erase_64kB(addr + pageoffset * 0x10000);
            ms_timer += flash_wait();
        }
        
        if (addr % (32*256) == 0) {
            Serial.printf("\n%3d%% @%06x writing: ", 100*addr/int(fp.size()), addr);
        }
        
        int n = std::min(256, int(fp.size()) - addr);
        uint8_t buffer[256];
        uint8_t file_buffer[256];

        //Serial.printf("write address %06x\r\n", addr);

        // read into file buffer
        for (int i = 0; i < n; i++) {
            int byte = fp.read();
            if (byte < 0) {
                Serial.printf("failed to read! addr %X", addr+i);
                break;
            }
            file_buffer[i] = byte;
        }
        
        bool write_success = false;
        for (int retry_count = 0; retry_count < 100; retry_count++)
        {
            flash_write_enable();
            flash_write(addr + pageoffset * 0x10000, file_buffer, n);
            ms_timer += flash_wait();
            
            flash_read(addr + pageoffset * 0x10000, buffer, n);

            if (!memcmp(buffer, file_buffer, n)) {
                Serial.printf("o");
                //goto written_ok;
                write_success = true;
                break;
            }
            
            Serial.printf("X");
        }
        
        if (!write_success) {
            // restart erasing and writing this 64kB sector
            addr -= addr % (64*1024);
            addr -= 256;
        }
    }
    
    Serial.printf("\n100%% total wait time: %d ms\r\n", ms_timer);
    power_down();
}

void init_spi()
{
    // initialize SPI interface
    pinMode(PI_ICE_CS, OUTPUT);
    digitalWrite(PI_ICE_CS, 1);
    SPI.begin();
}
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

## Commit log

2020-01-21 added tools
    [default_memory_set.csv, enable_table_pet.csv]
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2020-01-23 updated to 16 configurations
    [default_memory_set.csv, enable_table_pet.csv]
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2020-02-24 enable setting enable config in groups
    [enable_table_pet.csv]
2020-02-24 change 9000-AFFF passthrough region
    [enable_table_pet.csv]
2020-02-25 slow down read on programmer, prevent bit errors
    [programmer.cc]
2020-02-26 added modified edit roms for 8032
    [default_memory_set.csv]
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2020-03-04 Testing1 (#1)
    * added testing files
    * fixed makefile
    * added console test
    * fixed filename
    * adjust timing of console
    [default_memory_set.csv, enable_table_pet.csv]
2020-03-04 moved random_test.bin
    [default_memory_set.csv]
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2020-03-23 added custom editor memory set
    [sjg_edit_memory_set.csv]
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2020-03-24 added 2001 normal keyboard option
    [default_memory_set.csv]
2020-03-24 fixed rom
    [default_memory_set.csv]
2020-04-07 Mhill/update readme (#4)
    * fixed rom
    * updated switch settings
    [default_memory_set.csv]
2020-05-01 for pets without B000 rom, enable passthrough for B000-BFFF
    [enable_table_pet.csv]
2020-09-19 added memory map for apple ii plus
    [enable_table_pet_and_apple_ii_plus.csv, memory_set_with_apple_ii_plus.csv]
2020-09-23 memory maps for apple ii plus
    [default_memory_set.csv, enable_table_pet.csv]
2020-09-26 added 40 col/50 hz edit rom
    [default_memory_set.csv]
2020-10-02 added a test rom for testing motherboard roms
    [testrom.cfg]
2020-10-02 added zero page test
    [default_memory_set.csv, enable_table_pet.csv]
2020-10-04 ram check works
    [enable_table_pet.csv]
2020-10-04 makefile updates
    [default_memory_set.csv]
2020-10-06 added apple ii test program
    [default_memory_set.csv, enable_table_pet.csv]
2020-10-06 added apple ii test stuff
    [testrom_appleii.cfg]
2020-12-09 added rockwell aim-65 roms
    [default_memory_set.csv, enable_table_pet.csv]
2020-12-11 added 16k option for 4016
    [default_memory_set.csv, enable_table_pet.csv]
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2021-03-23 added settings for a PET 2001-8 board
    [pet_2001_8_enable_table.csv, pet_2001_8_memory_set.csv]
2021-03-25 more work on ram test, added pettest rom
    [pet_2001_8_enable_table.csv, pet_2001_8_memory_set.csv]
2021-03-26 added display to mem test
    [default_memory_set.csv, pet_2001_8_enable_table.csv, pet_2001_8_memory_set.csv]
2021-03-27 add config file
    [testromv2.cfg]
2021-03-28 added new rom and vram tester
    [romtester.cfg]
2021-03-28 ramtest compilation works
    [ramtest.cfg]
2021-03-29 fixed fetch rom script
    [ramtest.cfg]
2021-03-29 added ram and rom tests to pet 2001 setup
    [pet_2001_8_enable_table.csv, pet_2001_8_memory_set.csv, ramtest.cfg]
2021-03-29 added nop generator
    [pet_2001_8_enable_table.csv, pet_2001_8_memory_set.csv]
2021-03-31 added checksum to memory test
    [pet_2001_8_enable_table.csv]
2021-03-31 fixed edit rom on basic 2,4
    [pet_2001_8_enable_table.csv, pet_2001_8_memory_set.csv]
2021-05-06 added diag tools
    [default_memory_set.csv, enable_table_pet.csv]
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2021-05-12 added kicad project with programming diagram
    [programming.kicad_pcb, programming.sch]
2021-06-25 added apple ii plus
    [default_memory_set.csv, enable_table_pet.csv]
2021-06-25 fixed typo
    [default_memory_set.csv]
2021-06-27 update default memory maps
    [default_memory_set.csv]
2021-07-08 added ieee-488 test for PET
    [default_memory_set.csv, enable_table_pet.csv, ieee_test.cfg]
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2021-09-17 do not replace memory for PETTEST
    [enable_table_pet.csv]
2021-09-23 added vic-20 configurations
    [enable_table_vic20.csv, memory_set_vic20.csv]
2021-09-23 added CONFIG variable to makefile, renamed default setting files
    [enable_table_default.csv, memory_set_default.csv]
2021-09-23 added vic20 setting to default
    [enable_table_default.csv, memory_set_default.csv]
2021-09-26 fixed vic-20 configuration, added pal and ntsc version
    [enable_table_default.csv, memory_set_default.csv]
2021-10-05 updated vic20 settings
    [enable_table_vic20.csv, memory_set_vic20.csv]
2021-10-26 Add vram support (#7)
    * reading from vram is working
    * write and read fram working
    * add dual port ram
    * added parity check for screen transfer
    * added re-sending for 8 byte blocks of vram
    * added init file for vram
    * set max of 2048 bytes for vram
    * fix for vram sections in build_enable_table
    * cleaned up warnings
    * added make transfer
    * got configuration byte to read out properly
    * fixed selection of vram address start and end
    * separate libRomulatorDebug
    * rebuilt console
    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
    [enable_table_default.csv]
2021-11-12 added vram section to setting 5
    [enable_table_default.csv]
2021-11-20 Webserver character rom (#8)
    * add lookup table for character rom names
    * webserver update
    [enable_table_default.csv, enable_table_vic20.csv, memory_set_default.csv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]
2021-11-23 transfer address 59468 on PET to indicate which character bank to use
    [enable_table_default.csv]
2022-02-22 project for separate programming board
    [romulator-programmer-interface.kicad_pcb, romulator-programmer-interface.sch]
2022-03-02 new adapters
    [fpga_5v_pin_adapter.kicad_pcb, fpga_5v_pin_adapter.sch, romulator-programmer-interface.kicad_pcb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]
2022-03-07 fixed programmer board layout
    [romulator-programmer-interface.kicad_pcb, romulator-programmer-interface.sch]
2022-03-14 vram reading now working
    [enable_table_default.csv]
2022-03-16 display works on 80 columns
    [enable_table_default.csv]
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2022-03-29 added silkscreen on programmer pcb
    [romulator-programmer-interface.kicad_pcb]
2022-03-29 fixed build, server.h filename was confusing compiler
    [programmer_spi.cpp, rServer.cpp]
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2022-05-21 import everything from 6502
    [enable_table_default.csv]
2022-05-21 WIP ramenable table works
    [enable_table_default.csv]
2022-05-23 z80 ROM working, io working with wait
    [enable_table_default.csv, memory_set_default.csv]
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2022-05-30 support changing config indicies up to 31 in console (#10)
    update READMEs for 32 config indicies
    move and rename some config files to match convention
    [enable_table_pet_2001_8.csv, enable_table_pet_and_apple_ii_plus.csv, memory_set_pet_2001_8.csv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]
2022-06-21 added entries for trs80 m1 and ts 2068
    [enable_table_default_z80.csv, memory_set_default_z80.csv]
2022-06-22 new make targets for z80, clean up trs-80 model 1 config
    [enable_table_default_z80.csv, memory_set_default_z80.csv]
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2022-10-10 added config 17, 50hz 8032
    [enable_table_default.csv, memory_set_default.csv]
2022-10-10 validate user wifi settings, avoid accessing random data
    [rServer.cpp]
2023-12-23 add delay to ice reset in programmer utility
    [programmer_spi.cpp]
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2024-05-25 add reset before programming, prevents timeout crash
    [libRomulatorProgrammer.cpp, programmer_spi.cpp]

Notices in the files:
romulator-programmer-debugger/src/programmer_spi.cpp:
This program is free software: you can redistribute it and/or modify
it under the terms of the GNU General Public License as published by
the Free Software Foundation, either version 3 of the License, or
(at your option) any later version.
